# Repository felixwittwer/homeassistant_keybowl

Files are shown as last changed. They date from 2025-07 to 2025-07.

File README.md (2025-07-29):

<br>

<div align="center">

 &nbsp; &nbsp; 

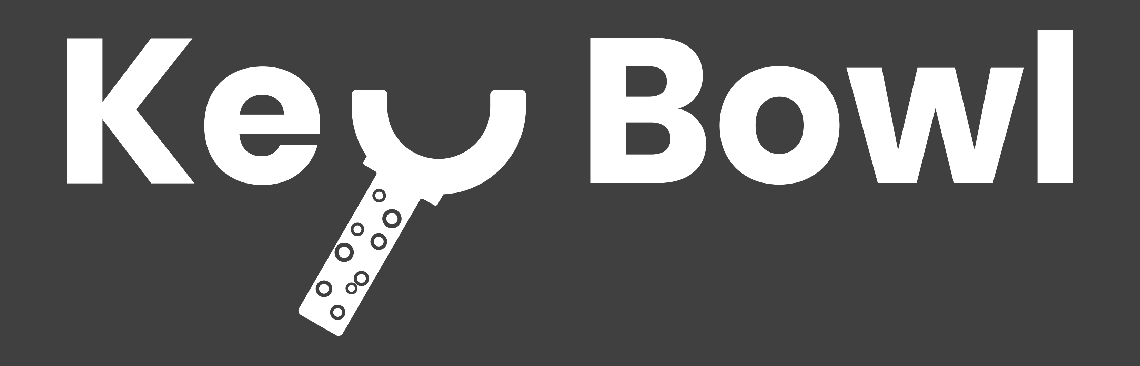
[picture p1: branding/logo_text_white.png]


</div>

<br>

# homeassistant_keybowl
a smart bowl for your keys with Homeassistant integration and a display to show simple dashoards.

## About the project

This project is smart keybowl where you can toss all your keys into and it will show you some interesting stuff from your Homeassistant instance. It simply hits you with the information you need when leaving home or comming back. The shown dashboards are custom for each user and are recognised by the RFID tag on each keychain.

The Keybowl should speed up your everyday routine by presenting you all the information you might have to look up in some app on your phone. For me personally my dashboard will contain a short version of the days timetable for school and its current changes for the day. When comming home it will probably display some stats of my servers.

The Keybowl siply will be a smart everday helper to make my and the life of others a bit easier and reduce the time you have to look up some information on your phone.

## The Project

### PCB

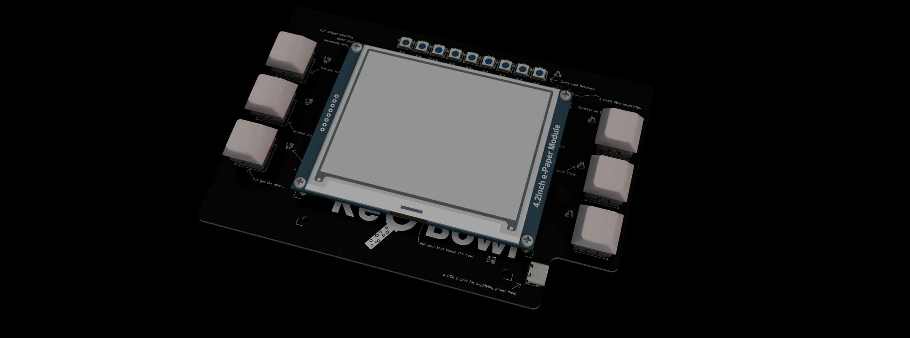
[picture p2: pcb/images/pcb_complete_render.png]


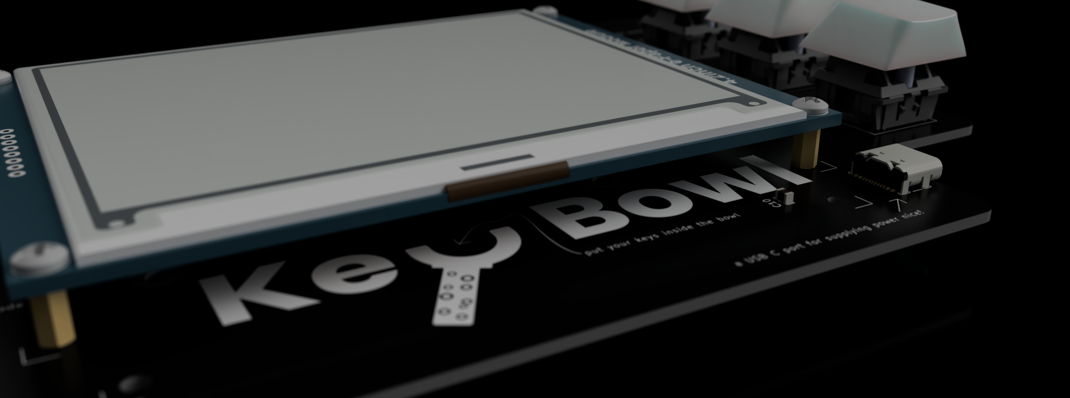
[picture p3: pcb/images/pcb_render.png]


<p float="left">
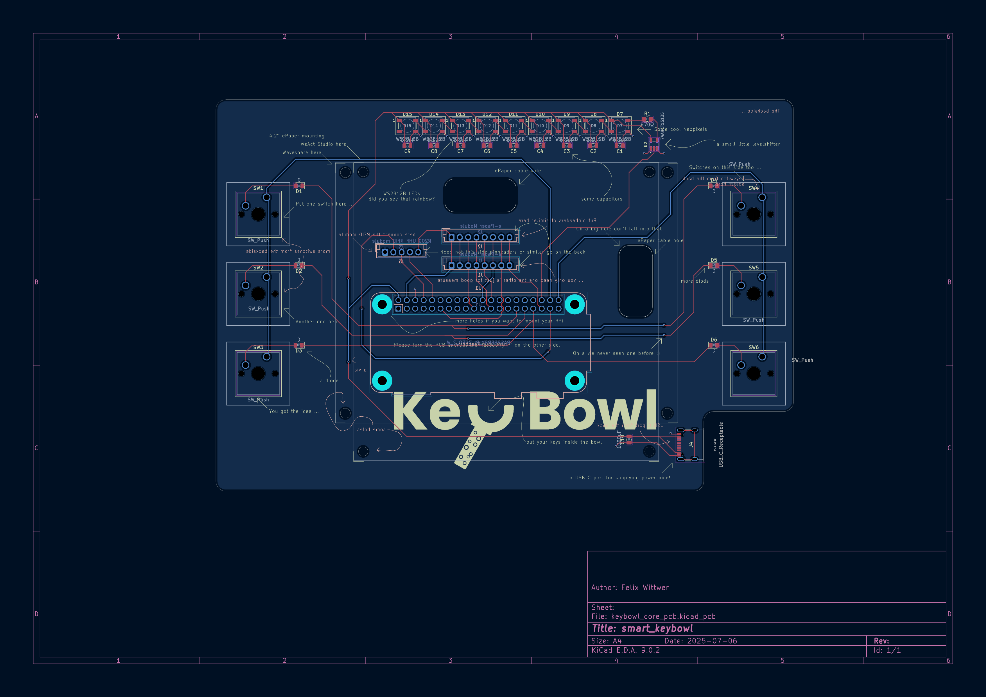
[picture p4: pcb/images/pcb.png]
  
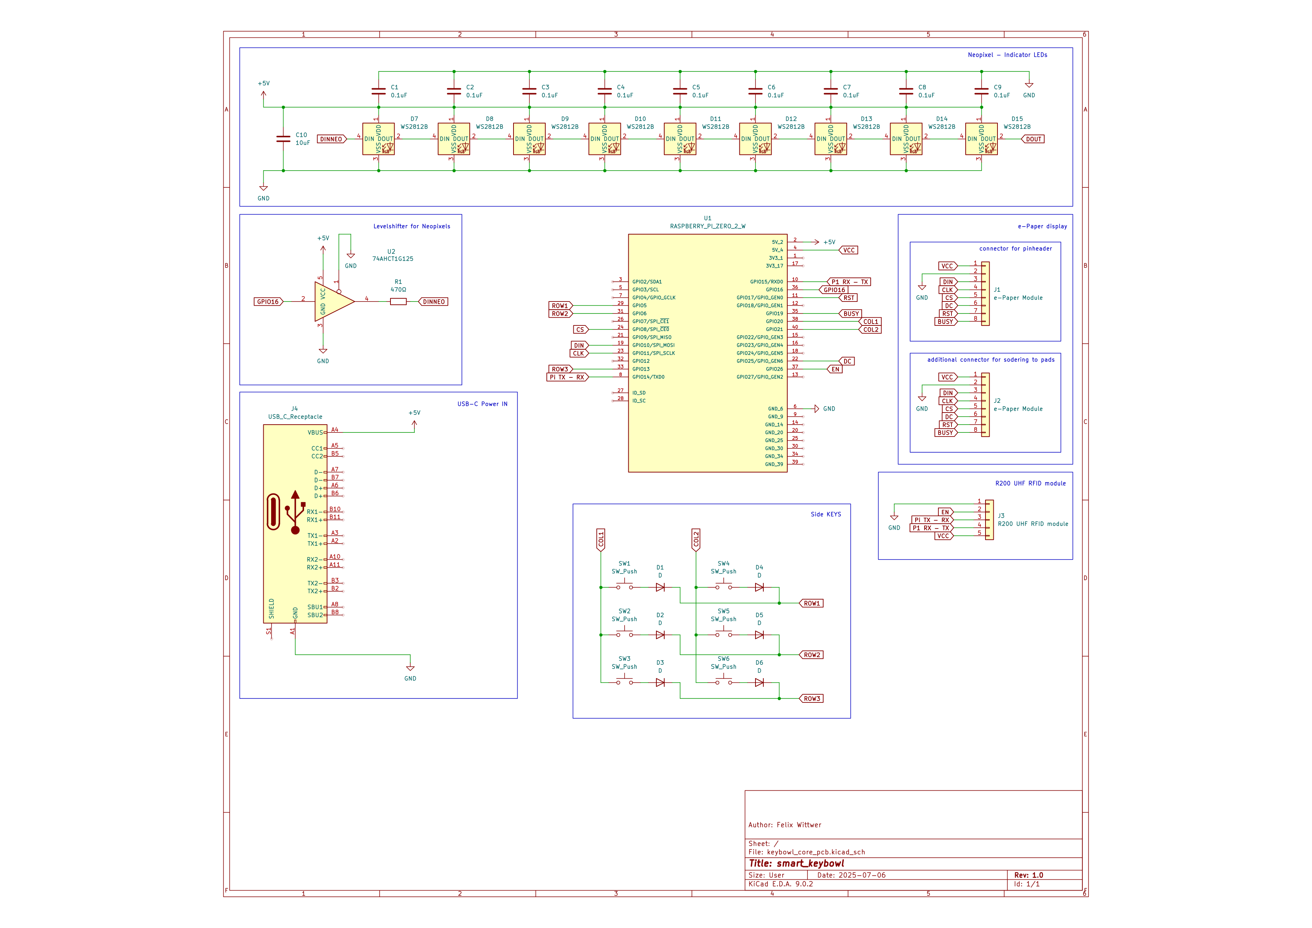
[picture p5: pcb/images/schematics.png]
  
</p>

Be aware that some parts on the rende will not be populated on the PCB because they are not really needed but may be in the future or while I am building the project so for futureprovness the are on in the pcb design and in the rendered images. Have a look at the BOM so se which parts are ment and be aware to bridge the if they are not populated.

### complete assembly

A screenshot of the whole project. Sorry no beautiful render fusions standard wood textures look just ugly :(.

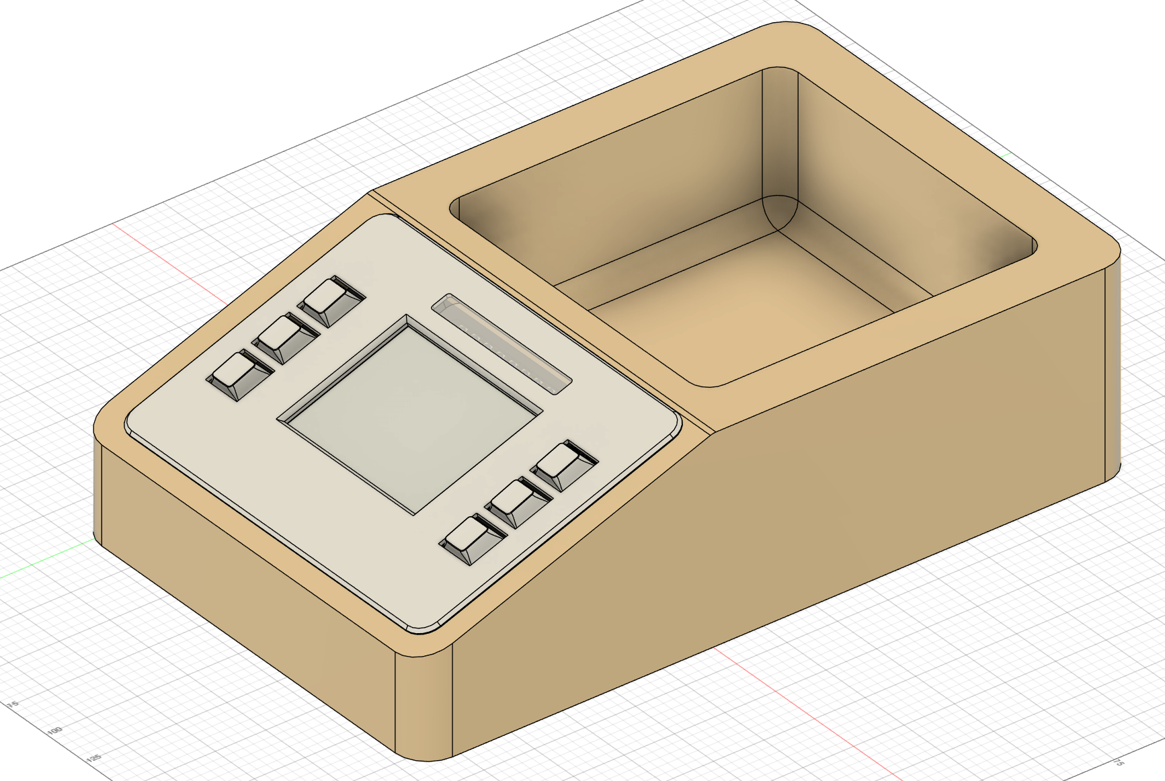
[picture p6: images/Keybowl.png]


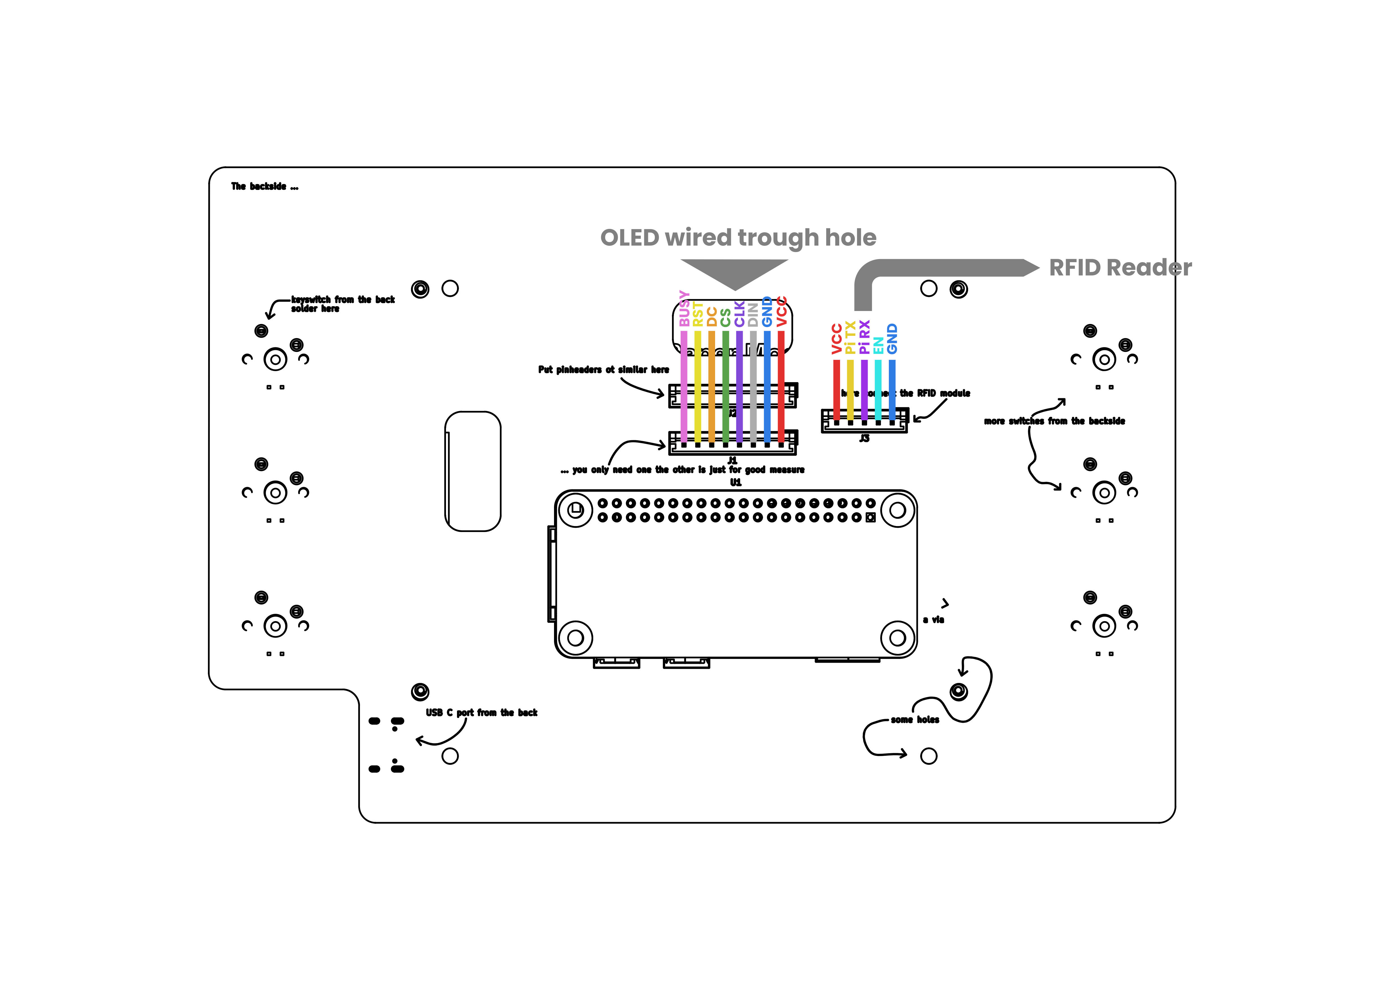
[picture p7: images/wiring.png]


### CAD 

All CAD files can be found inside the [cad](./cad/) directory

[keybowl_complete](./cad/Keybowl%20complete.step) is the whole project and the other files are individual parts of the complete project.

### Firmware

Detailed instructions on how to setup the firmware can be found inside the [firmware folders README](./firmware/README.md)

## BOM

### Aliexpress (for Highway)

**total:** 141.60 USD

| part name | amount | price | link | note |
| --- | --- | ----- | ---- | ---- |
| UHF RFID Module 1dbi 35x35mm | 1 | 39.27 USD | https://de.aliexpress.com/item/1005008307223636.html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 | |
| 4.2inch e-paper | 1 | 29.38 USD | https://de.aliexpress.com/item/1005005825856739.html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 | would have liked to choose another one but waveshare has the best documentation and if you decide to upgrade the displays have the same footprint (upgrading from 4 grayscale to black/white/red possible)|
| Raspberry Pi Zero 2 W | 1 | 20.57 USD | https://de.aliexpress.com/item/1005008147614202.html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 | Pi Zero needed because of Homeassistant integration and connectivity (ESP32-S3 can't quite manage all this stuff together) |
| RFID tags | 5pcs | 0.99 USD | https://de.aliexpress.com/item/1005008292479936.html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
| keyswitches | 6 | 1.19 USD | https://de.aliexpress.com/item/1005005371211477.html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 | come as 10 pcs set |
| basic DSA Keycaps | 6 | 1.19 USD | https://de.aliexpress.com/item/1005006005905021.html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 | come as 20 pcs set |
| PCB and PCBA | 1 | ~ 50 USD |  https://jlcpcb.com/ | price is subject to JLCs review |

**--- PCB Assembly stuff if you want to populate yourself (prices from JLC PCBA) ---**
| part name | amount | price | link | note |
| --- | --- | ----- | ---- | ---- |
| capacitor 0.1 uF | 9 | $0.1254 | https://jlcpcb.com/partdetail/C30926 | ---- |
| WS2812B LEDs | 9 | $2.3471 | https://jlcpcb.com/partdetail/C2843785 | ---- |
| diodes | 6 | $0.4644 | https://jlcpcb.com/partdetail/C24372 | ---- |
| | total | 2,9369 USD

<br>
optional parts (will not be populated) keep in mind to bridge footprints

| part name | amount | price | link | note |
| --- | --- | ----- | ---- | ---- |
| capacitor 10uF  | 1 | $0.1098 | https://jlcpcb.com/partdetail/C39060 | ---- |
| Levelshifter 74AHCT1G125 | 1 | $0.3820 | https://jlcpcb.com/partdetail/C842287 | ---- |
| Resistor 470 ohm | 9 | $0.0300 | https://jlcpcb.com/partdetail/C21266 | ---- |
| usb-c connector | 1 | 0.99 USD | https://de.aliexpress.com/item/1005008164395076.html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 | ----
| | total | 1,5118 USD

**total:** 141.60 USD

<br>
<br>
for people who don't want to order via aliexpress or simply can't here is a BOM with mostly amazon equivalients

### Amazon (mostly)

**total:** 192.48 USD

| part name | amount | price | link | note |
| --- | --- | ----- | ---- | ---- |
| UHF RFID Module 1dbi 35x35mm | 1 | 39.27 USD | https://de.aliexpress.com/item/1005008307223636.html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 | | 
| 4.2inch e-paper | 1 | 54.08 USD | https://www.amazon.de/dp/B074NR1SW2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 | would have liked to choose another one but waveshare has the best documentation and if you decide to upgrade the displays have the same footprint (upgrading from 4 grayscale to black/white/red possible)| 
| Raspberry Pi Zero 2 W | 1 | 26.93 USD | https://www.amazon.de/Raspberry-Pi-Zero-2-W/dp/B09KLVX4RT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 | Pi Zero needed because of Homeassistant integration and connectivity (ESP32-S3 can't quite manage all this stuff together) |
| RFID tags | 5pcs | 7.95 USD | https://www.amazon.de/YARONGTECH%C2%AE-RFID-13-56-MIFARE-Classic/dp/B0749LSMLH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
| keyswitches | 6 | 8.55 USD | https://www.amazon.de/Topiky-mechanische-Tastatur-Schalter-RGB-Serie-default/dp/B07Q6YJ2GS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 | come as 10 pcs set |
| basic DSA Keycaps | 6 | 5.70 USD | https://www.amazon.de/Transparent-Keycaps-Mechanical-Keyboard-Clearance/dp/B0CJLS9GGP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 | come as 10 pcs set |
| PCB and PCBA | 1 | ~ 50 USD |  https://jlcpcb.com/ | price is subject to JLCs review |

**total:** 192.48 USD

## Credits

Raspberry Pi Zero Symbol, Footprint and 3D-Model for KiCad: https://www.snapeda.com/parts/RASPBERRY%20PI%20ZERO%202%20W/Raspberry%20Pi/view-part/?welcome=home

Waveshare 4.2inch e-Paper Module CAD: https://grabcad.com/library/waveshare-4-2-e-paper-module-1

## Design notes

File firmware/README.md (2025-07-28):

# Firmware

This is a small guide about the structure of the firmware and how to install it on your pi zero 2.

## structure

low level code for all the individual parts

**-> components**

some routines

**-> routines**

the dashboards to show

**-> dashboards**

besides the folder there is the **main.py** which is the main script that needs to be executed. 

## setup the firmware

### General and Python Setup 

Install Raspberry Pi OS Lite

``` bash
sudo apt update && sudo apt upgrade -y
sudo apt install python3 python3-pip git
```

### clone the Repo

``` bash
git clone https://github.com/felixwittwer/homeassistant_keybowl.git
```

``` bash
cd homeassistant_keybowl
```

### Install the required python packages

``` bash
pip install -r requirements.txt
```

### Enable I2C and Serial

``` bash
sudo raspi-config
```

- (enable I2C)
- enable Serial (disable shell, enable hardware serial)

Reboot!

### SPI Setup

- Make sure SPI is enabled on your Pi

``` bash
sudo raspi-config
```
(Interface Options -> SPI -> Enable)

Reboot if asked!

- confirm SPI device nodes:
``` bash
ls /dev/spidev0.*
```

### MQTT Setup for Homeassistant

(this command is not really neadded when you installed everything via the requirements.txt)

``` bash
pip install paho-mqtt
```

Inside Homeassistant make sure you have a MQTT Broker like Mosquitto installed and enabled.

### Neopixel Setup

``` bash
sudo pip install rpi_ws281x adafruit-circuitpython-neopixel
sudo python -m pip install --force-reinstall adafruit-blinka
```

### Run the firmware

``` bash
python3 main.py
```

### Setup autostart on boot

open with

``` bash
sudo nano /etc/rc.local
```

and add :
``` bash
python3 /home/pi/homeassistant_keybowl/main.py 
```

above exit 0

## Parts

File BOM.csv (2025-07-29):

part name | amount | price | link | note
UHF RFID Module 1dbi 35x35mm | 1 | 39.27 USD | https://de.aliexpress.com/item/1005008307223636.html?pdp_ext_f={"order"%3A"8"%2C"eval"%3A"1"}&utparam-url=scene%3Asearch|query_from%3A
4.2inch e-paper | 1 | 29.38 USD | https://de.aliexpress.com/item/1005005825856739.html?pdp_ext_f={"order"%3A"13"%2C"eval"%3A"1"}&utparam-url=scene%3Asearch|query_from%3A | would have liked to choose another one but waveshare has the best documentation and if you decide to upgrade the displays have the same footprint (upgrading from 4 grayscale to black/white/red possible)
Raspberry Pi Zero 2 W | 1 | 20.57 USD | https://de.aliexpress.com/item/1005008147614202.html?pdp_ext_f={"order"%3A"141"%2C"eval"%3A"1"}&utparam-url=scene%3Asearch|query_from%3A
RFID tags | 5 | 0.99 USD | https://de.aliexpress.com/item/1005008292479936.html?pdp_ext_f={"order"%3A"24"%2C"eval"%3A"1"}&utparam-url=scene%3Asearch|query_from%3A | Pi Zero needed because of Homeassistant integration and connectivity (ESP32-S3 can't quite manage all this stuff together)
keyswitches | 6 | 1.19 USD | https://de.aliexpress.com/item/1005005371211477.html?pdp_ext_f={"order"%3A"13"%2C"eval"%3A"1"}&utparam-url=scene%3Asearch|query_from%3A | come as 20 pcs set
basic DSA Keycaps | 6 | 1.19 USD | https://de.aliexpress.com/item/1005006005905021.html?pdp_ext_f={"order"%3A"525"%2C"eval"%3A"1"}&utparam-url=scene%3Asearch|query_from%3A | come as 20 pcs set
PCB and PCBA | 1 | ~ 50 USD | https://jlcpcb.com/ | price is subject to JLCs review
total |  | 141.16 USD

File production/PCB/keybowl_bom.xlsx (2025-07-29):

Comment | Designator | Footprint | JLCPCB Part #?optional?
0.1uF | C7,C4,C5,C8,C6,C1,C9,C2,C3 | C_0805_2012Metric | C30926
WS2812B | D9,D11,D10,D7,D12,D13,D8,D15,D14 | LED_WS2812B_PLCC4_5.0x5.0mm_P3.2mm | C2843785
D | D5,D2,D3,D4,D1,D6 | D_0805_2012Metric | C24372
10uF | C10 | C_0805_2012Metric | C39060
74AHCT1G125 | U2 | SOT95P280X145-5N | C842287
470ohm | R1 | R_0805_2012Metric_Pad1.20x1.40mm_HandSolder | C21266

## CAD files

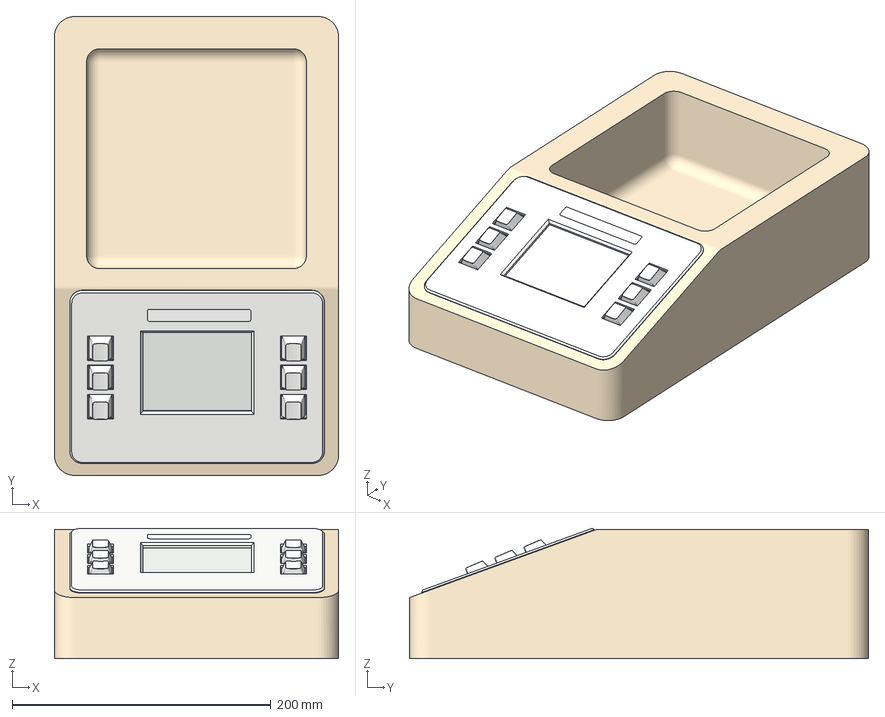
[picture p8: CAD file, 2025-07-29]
cad/Keybowl complete.3mf
220.0 x 355.0 x 100.8 mm
Körper1 x 107
Körper10 x 10
Körper100 x 3
Körper101 x 3
Körper102 x 3
Körper103 x 3
Körper104 x 3
Körper105 x 3
Körper106 x 3
Körper107 x 3
Körper108 x 3
Körper109 x 3
Körper11 x 10
Körper110 x 3
Körper111 x 3
Körper112 x 3
Körper113 x 3
Körper114 x 3
Körper115 x 3
Körper116 x 3
Körper117 x 3
Körper118 x 3
Körper119 x 3
Körper12 x 10
Körper120 x 3
Körper121 x 3
Körper122 x 3
Körper123 x 3
Körper124 x 3
Körper125 x 3
Körper126 x 3
Körper127 x 3
Körper128 x 3
Körper129 x 3
Körper13 x 10
Körper130 x 3
Körper131 x 3
Körper132 x 3
Körper133 x 3
Körper134 x 3
Körper135 x 3
Körper136 x 3
Körper137 x 3
Körper138 x 3
Körper139 x 3
Körper14 x 10
Körper140 x 3
Körper141 x 3
Körper142 x 3
Körper143 x 3
Körper144 x 3
Körper145 x 3
Körper146 x 3
Körper147 x 3
Körper148 x 3
Körper149 x 3
Körper15 x 10
Körper150 x 3
Körper151 x 3
Körper152 x 3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

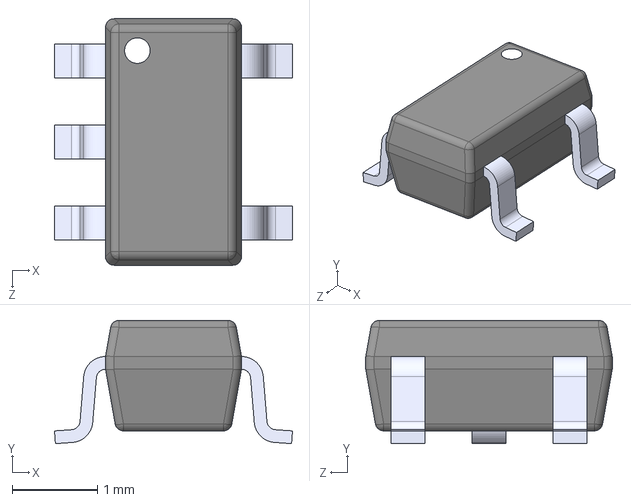
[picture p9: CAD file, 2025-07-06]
pcb/keybowl_core_pcb/SN74AHCT1G125DBVR/SN74AHCT1G125DBVR.step
2.80 x 1.45 x 2.90 mm

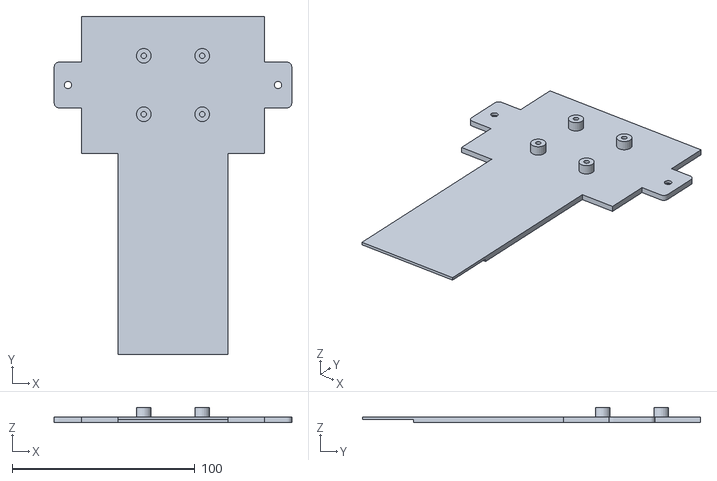
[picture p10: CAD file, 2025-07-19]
production/3D printing/rfid_support.stl
130.0 x 185.0 x 8.00

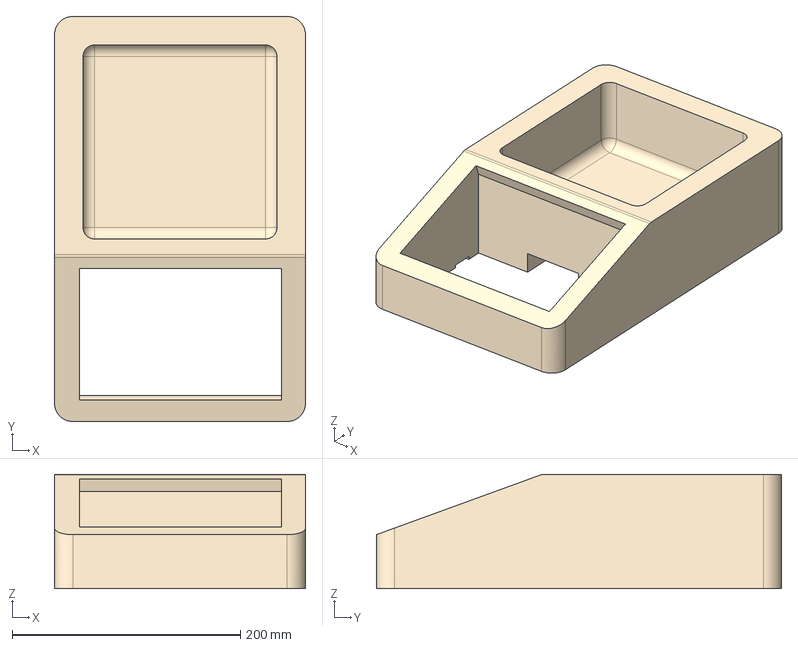
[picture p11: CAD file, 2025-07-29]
cad/bowl.step
220.0 x 355.0 x 100.0 mm

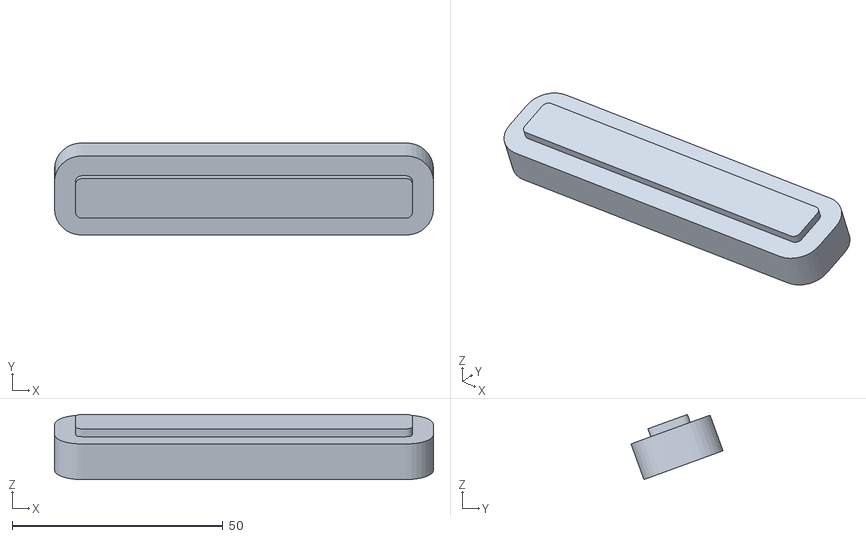
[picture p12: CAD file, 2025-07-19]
production/3D printing/nepixel_diffusor.stl
90.0 x 21.9 x 15.5

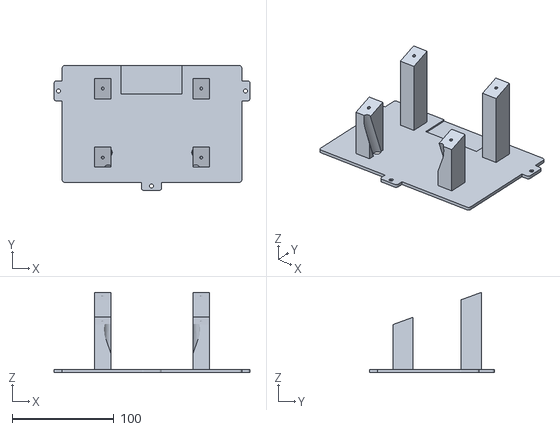
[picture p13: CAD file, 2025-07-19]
production/3D printing/pcb_support.stl
193.0 x 123.0 x 78.9

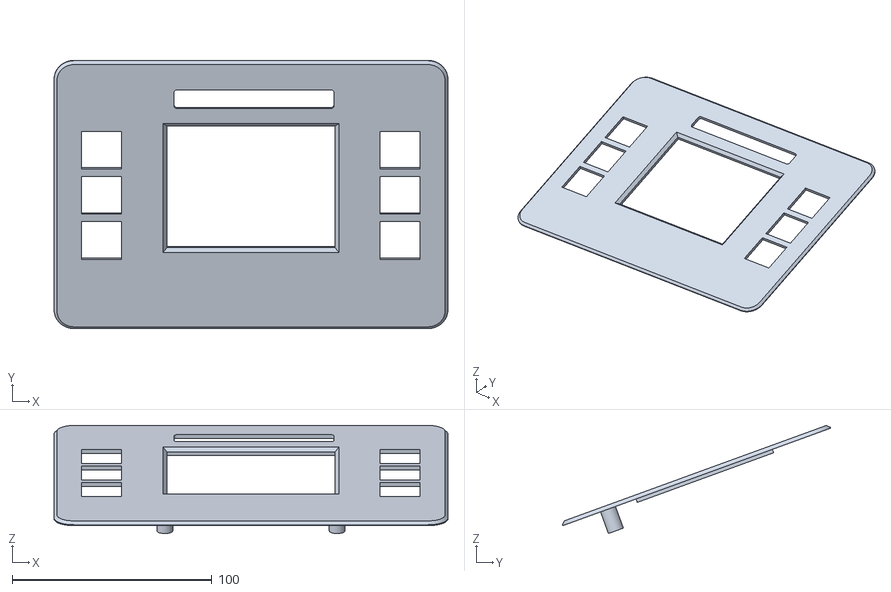
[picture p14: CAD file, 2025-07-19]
production/3D printing/bezzle.stl
197.0 x 134.1 x 54.0

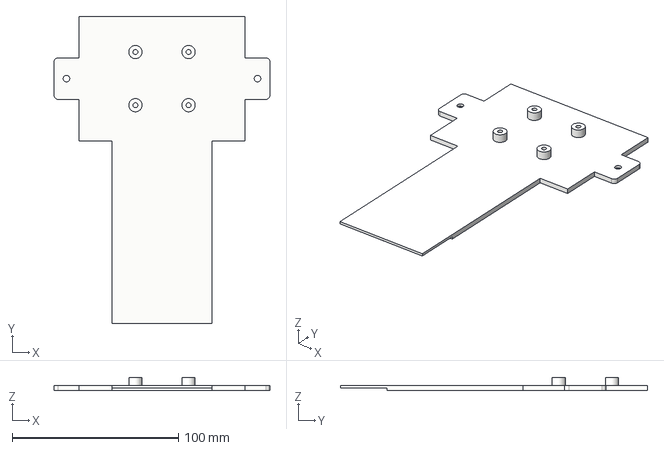
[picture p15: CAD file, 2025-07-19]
cad/rfid_support.step
130.0 x 185.0 x 8.00 mm

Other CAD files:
cad/neopixel_diffusor.step
cad/pcb_support.step
cad/bezzle.step

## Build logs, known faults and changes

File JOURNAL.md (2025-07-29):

---
title: "Homeassistant KEYBOWL"
author: "Felix Wittwer (fegolix)"
description: "A keybowl designed for all your keys. But smart."
created_at: "2024-07-06"
---

# Journal

Here you can see a documentation of the entire development process.

**Total hours spent: 26h**

## July 6th (7h)

### Session 1 (2h) getting the idea, researching

After searcing for my keys and not finding them in our "key bowl" I got the idea of a smart solution for our keys. And even better how to integrate that into Homeassistant. Forst of all the concept. So the normal non smart version is preitty simple, just toss all your keys into a borwl/ basket but what if every keychain had an RFID tag on it? This would allow for thracking the keys not neccesarily to spy on wh is home wut to knwo where the keys are. To step it up a bit this could also be integrated into Homeassistant with a small display that shows some data/dashboard per user. Everyone has his own keychain so I can track who tossed his key in or took it out. And based on that information everybody gets shown his own personal dashboard. For one it might be stats about our greenhouse for the othe their timetable and current changes of it right in the morning before school.

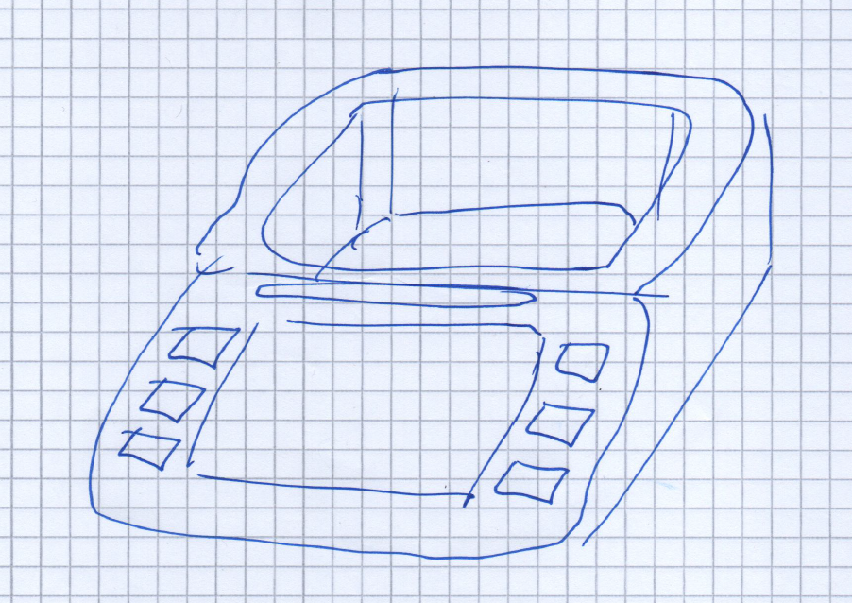
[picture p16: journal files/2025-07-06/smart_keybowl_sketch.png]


<br>

I wanted a simple non distracting and simple solution that doesn't uses to much power and in standby mode maybe can be used as a clock. So I opted for a 4.2 inch e-Paper display and a raspberry Pi Zero 2 which is relatively low cost but has enough power to handle all the stuff of the display, additional keys and RFID reader and can render beautiful layouts on the screen. An ESP32-S3 simply cant handel all of that in an easy way. Another chalenge was finding the right module and corresponding RFID Tags. NFC simply wouldn't cut it here. I needed a solution that can read multiple tags at one inside a pile and that without errors. This lead me to the R200 module a UHF RFID Reader.

### Session 2 (5h) starting PCB design

After researching all the parts I started with the core PCB which is kind of a HAT for the Raspberry Pi Zero 2 and will be in the middle of the case. Everything else will be designed arround it. To make it a bit extra I added a bar of neopixels above the display this will later be usefull to show status or be indicator LEDs. Because I quite like habtical buttons I added three on each side of the display. These will later be for navigating on the display of showing specific dashboards. These additions make the whole thing a bit mode interesting so now it is not "just a display" :).

This time I really tried making my schematics a bit better than the last one. I think it is quite organised. Another challenge for me was learing on how to use a ground plane which I have never done befoder but eventually got it working.

<p float="left">
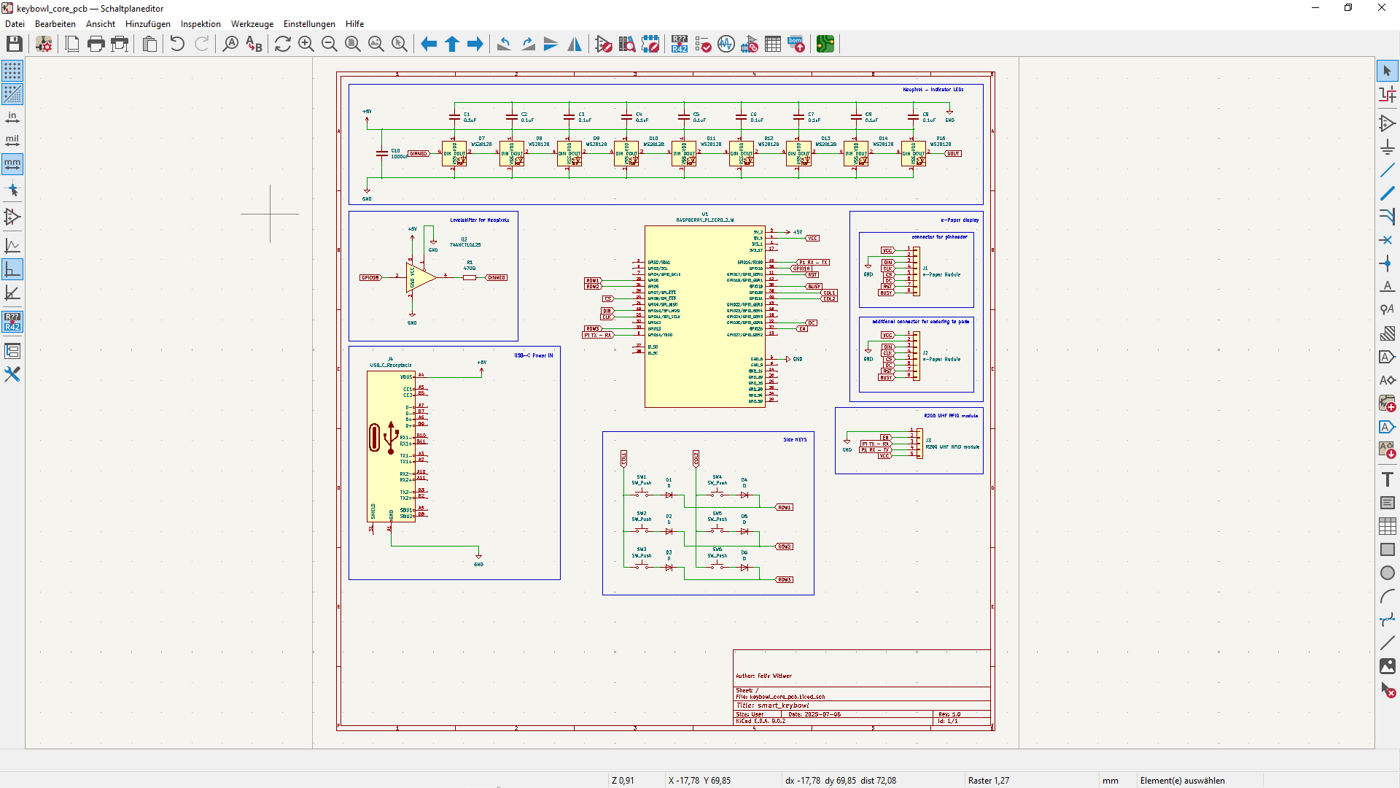
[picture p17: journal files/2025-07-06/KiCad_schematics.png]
  
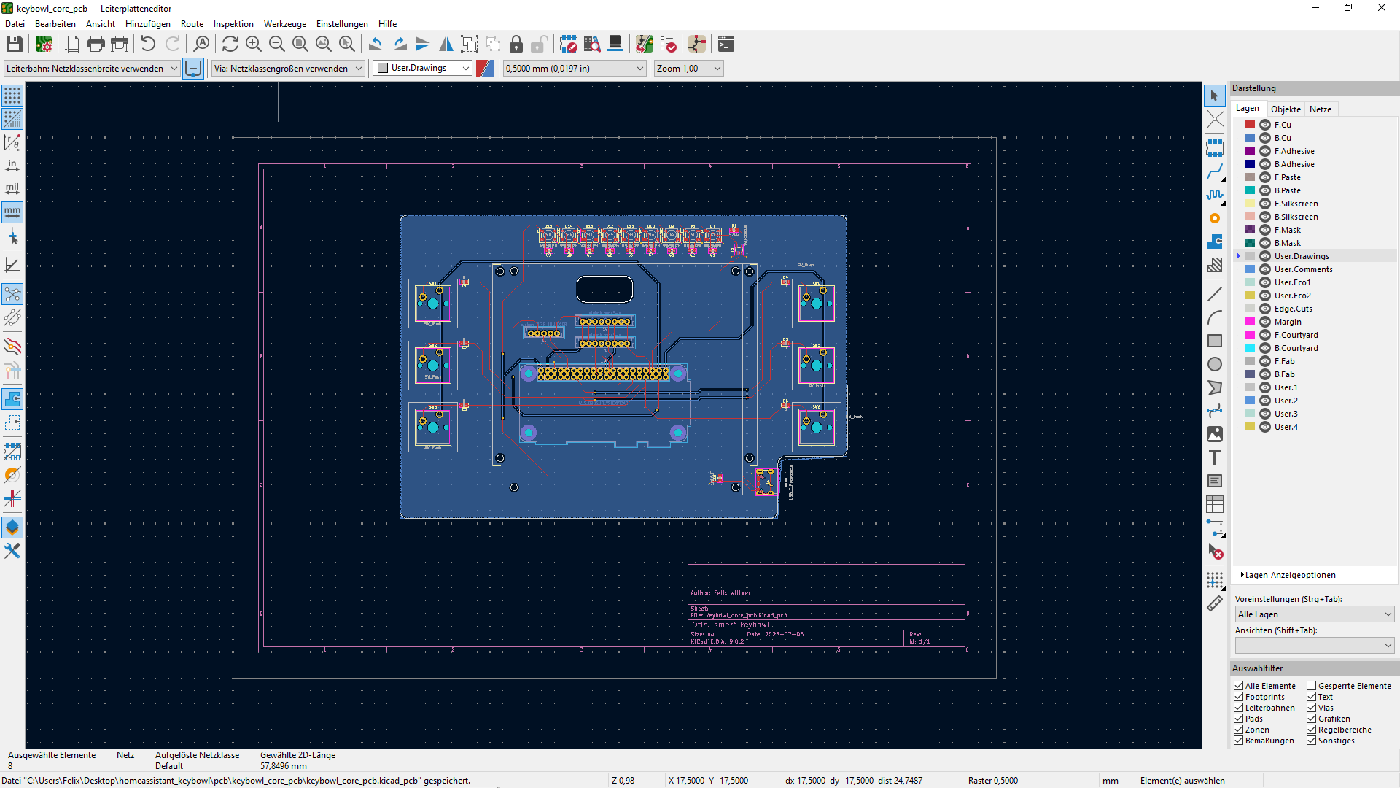
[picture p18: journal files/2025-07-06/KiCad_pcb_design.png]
  
</p>

## July 8th (2h)

### Session 1 (1h) adding some branding

Every project need some branding and I need some logos to make the PCB beautiful :). Logo is made with Inkscape.

<p float="left">
  
</p>

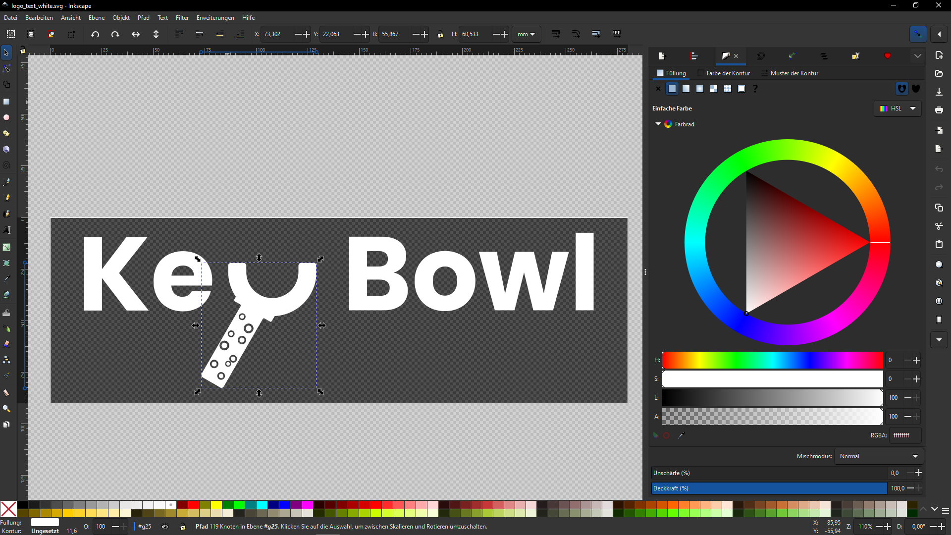
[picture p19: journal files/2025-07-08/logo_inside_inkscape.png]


### Session 2 (1h) working on the PCB

Now with a cool logo I could work further on the PCB. After adding the logo it seemed still a bit empty to me so I added some cool notes. If somebody else that me is going to assemlble this he is going to have some fun. AN jeah I defenitely discovered the path feature for the siklscreen lines/arrows. Some engenieet at JLC is going to get crazy after seeing my silkscreen :).

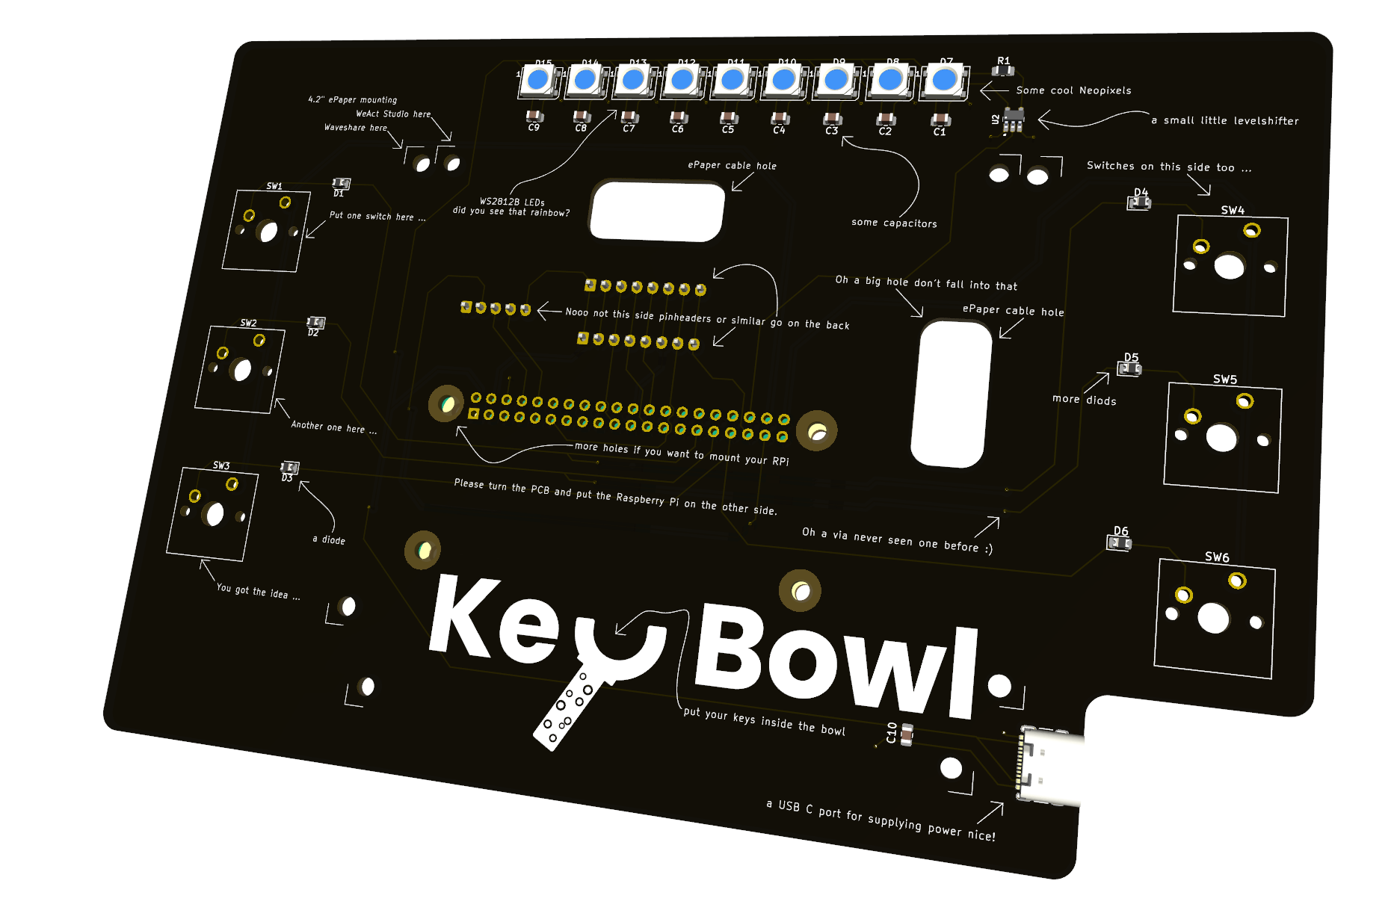
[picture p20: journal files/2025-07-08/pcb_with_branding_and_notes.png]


## July 18th (1h) assemble pcb in Fusion

Today I just exported the PCB from KiCad as a STEP to Fusion and sarted putting all the pars on it. The next step will be to design the keybowl itself and place the PCB inside. The Keybowl itself will porbably be made out of Wood with some small 3D printed parts like a bezzle around the screen and keyswitches.

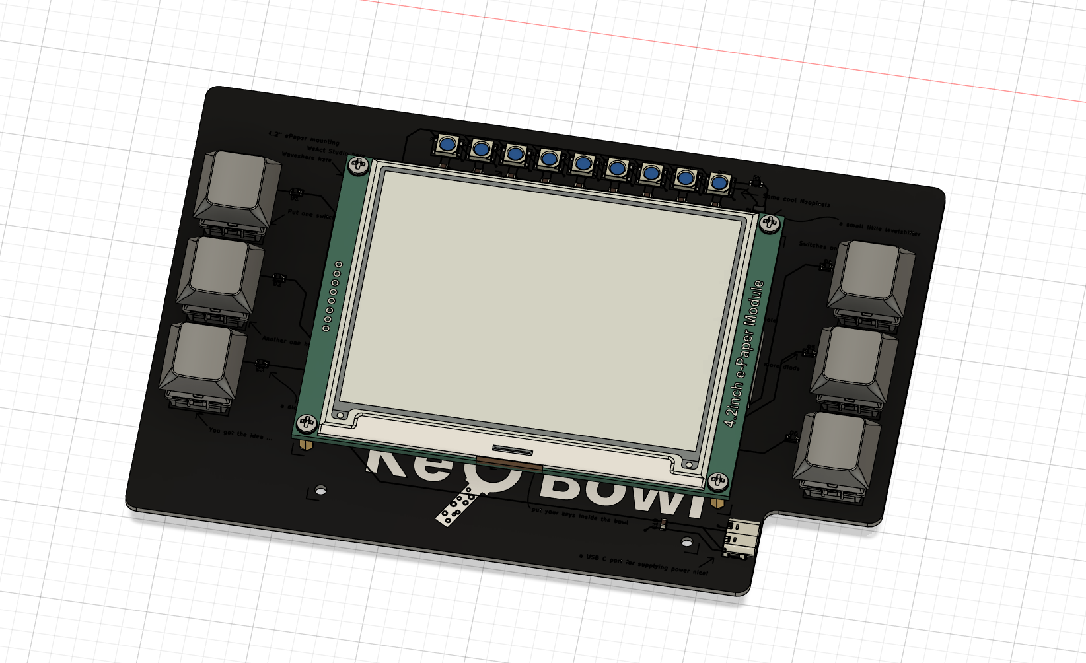
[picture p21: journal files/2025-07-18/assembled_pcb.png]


## July 19th (5h)

### Session 1 (4h) modeling the case

After creating a model of the assembled PCB I designed a housing around it. The main hosusing will be made out of wood only the parts for holding the PCb, RFID reader and the bezzle will be 3D printed. I designed the bezzle in such a way that it lays over the part that will be removed with a roter so if I mess up there it is at least not hidden. The parts fo the PCB and RFID mounting are also seperate to that these can be changed independently. So if someone chooses a bigger RFID reader not the whole structer needs to be reprinted. It also took me a while to figure out how I can mount everything while also making it possible to assemble. If the PCB is mouted inside the housing you can not reach the screws of the bezzle. Therefore I mad some additional holes inside the mounting to make the screws actually reachable.  

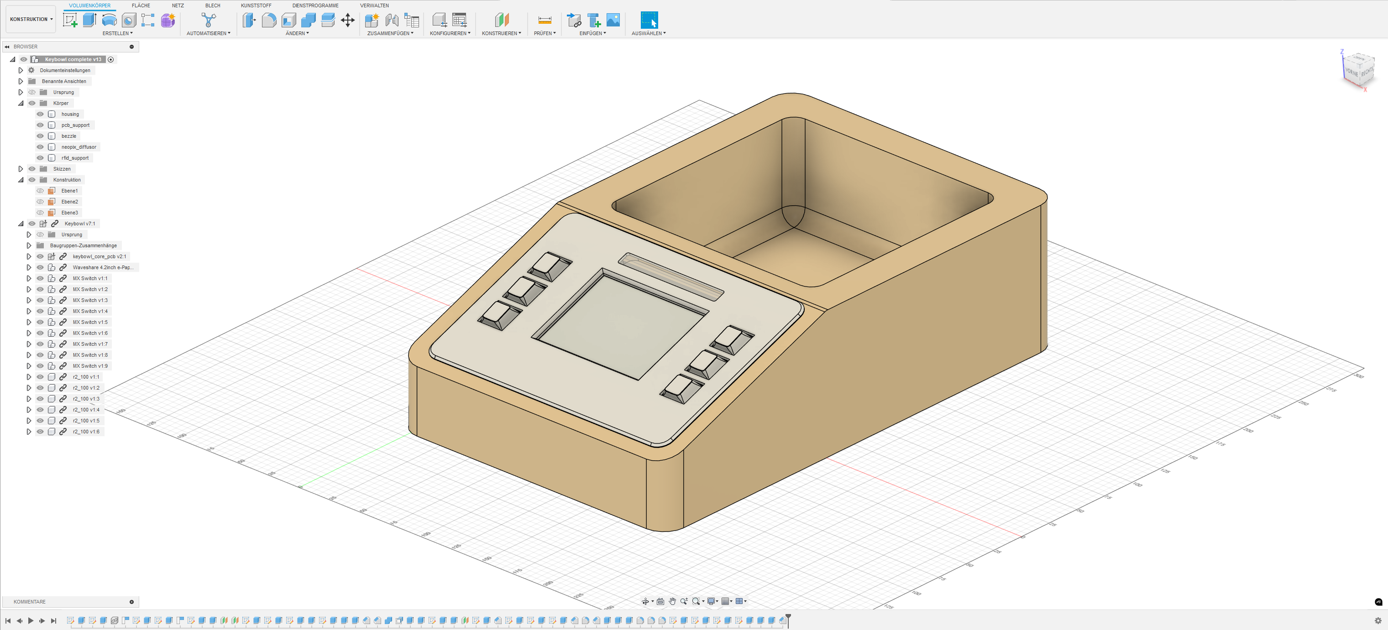
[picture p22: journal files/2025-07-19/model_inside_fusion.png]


<p float="left">
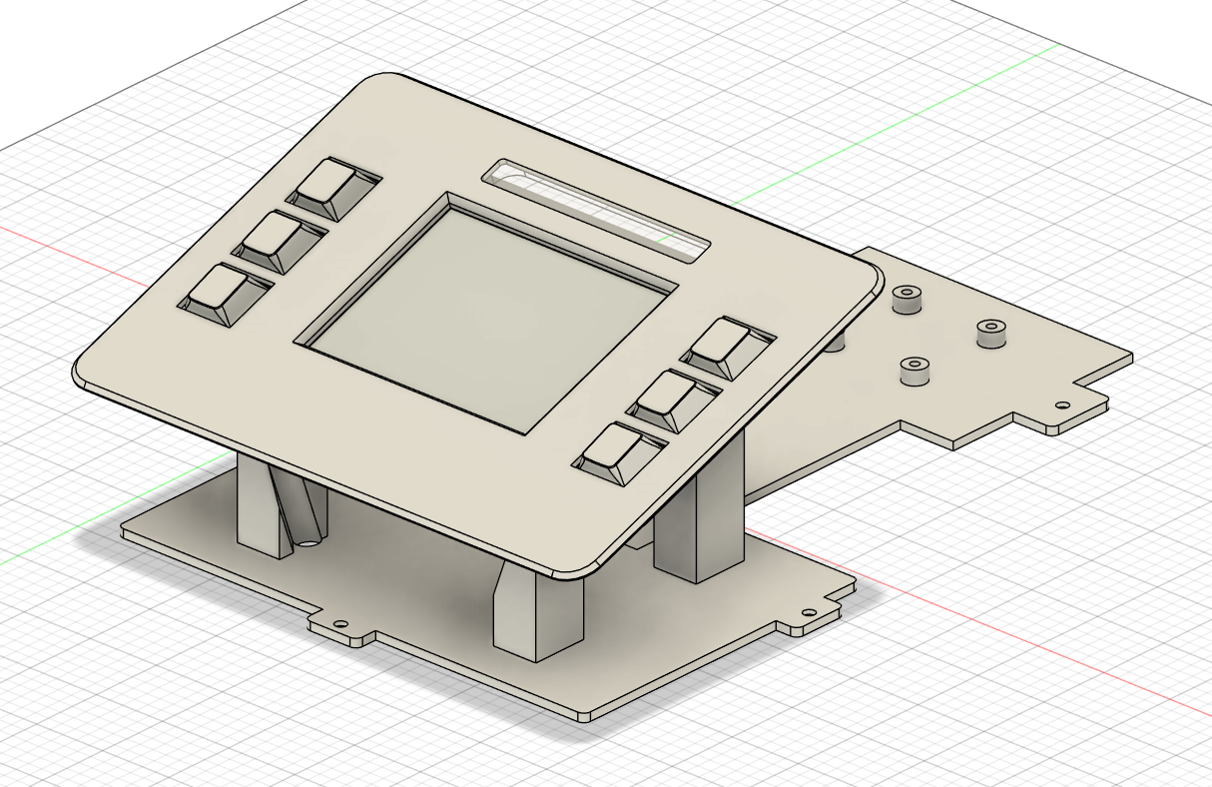
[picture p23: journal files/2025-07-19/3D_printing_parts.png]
  
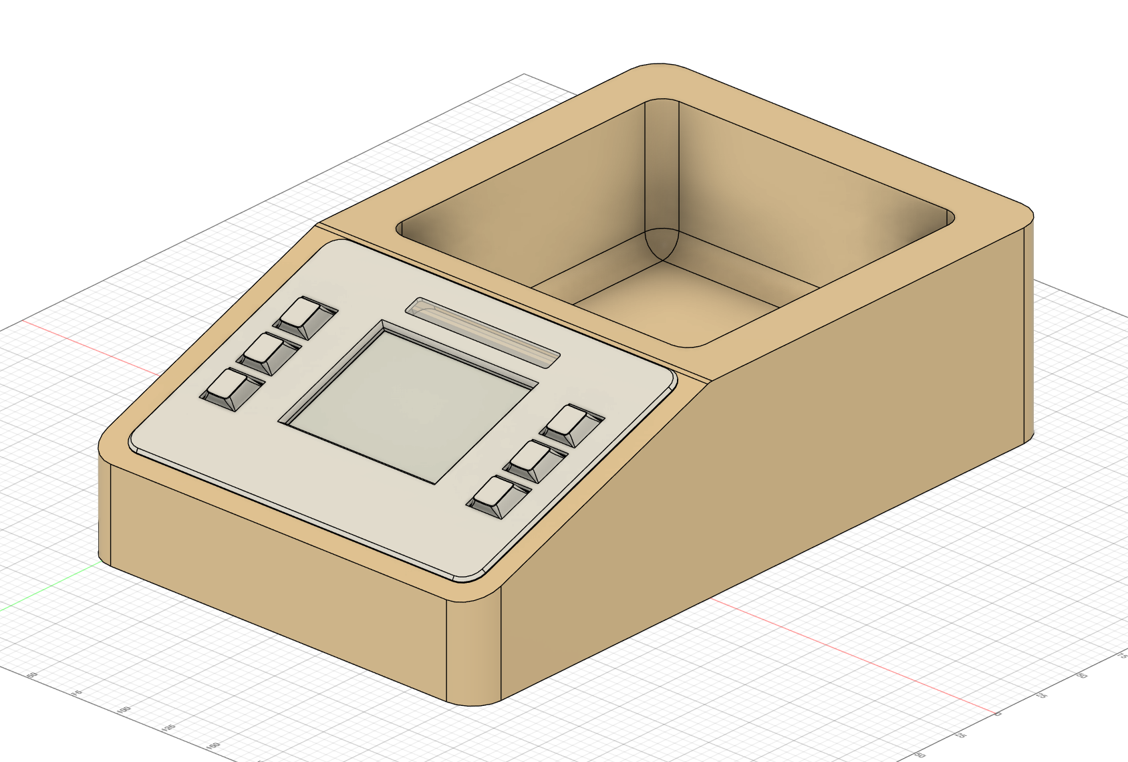
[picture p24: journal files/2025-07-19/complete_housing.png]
  
</p>

### Session 2 (1h) creating production files and manufacturing instructions

I hav now created a stl file and step file for each part so that they can easily be 3D printed. Because recreating the woodden base if you have not designed it is pretty difficult I created some drawings with whom anybody can build the main housing. If you have large enough 3D printer you could probably also just print it but wood looks a bit nicer.

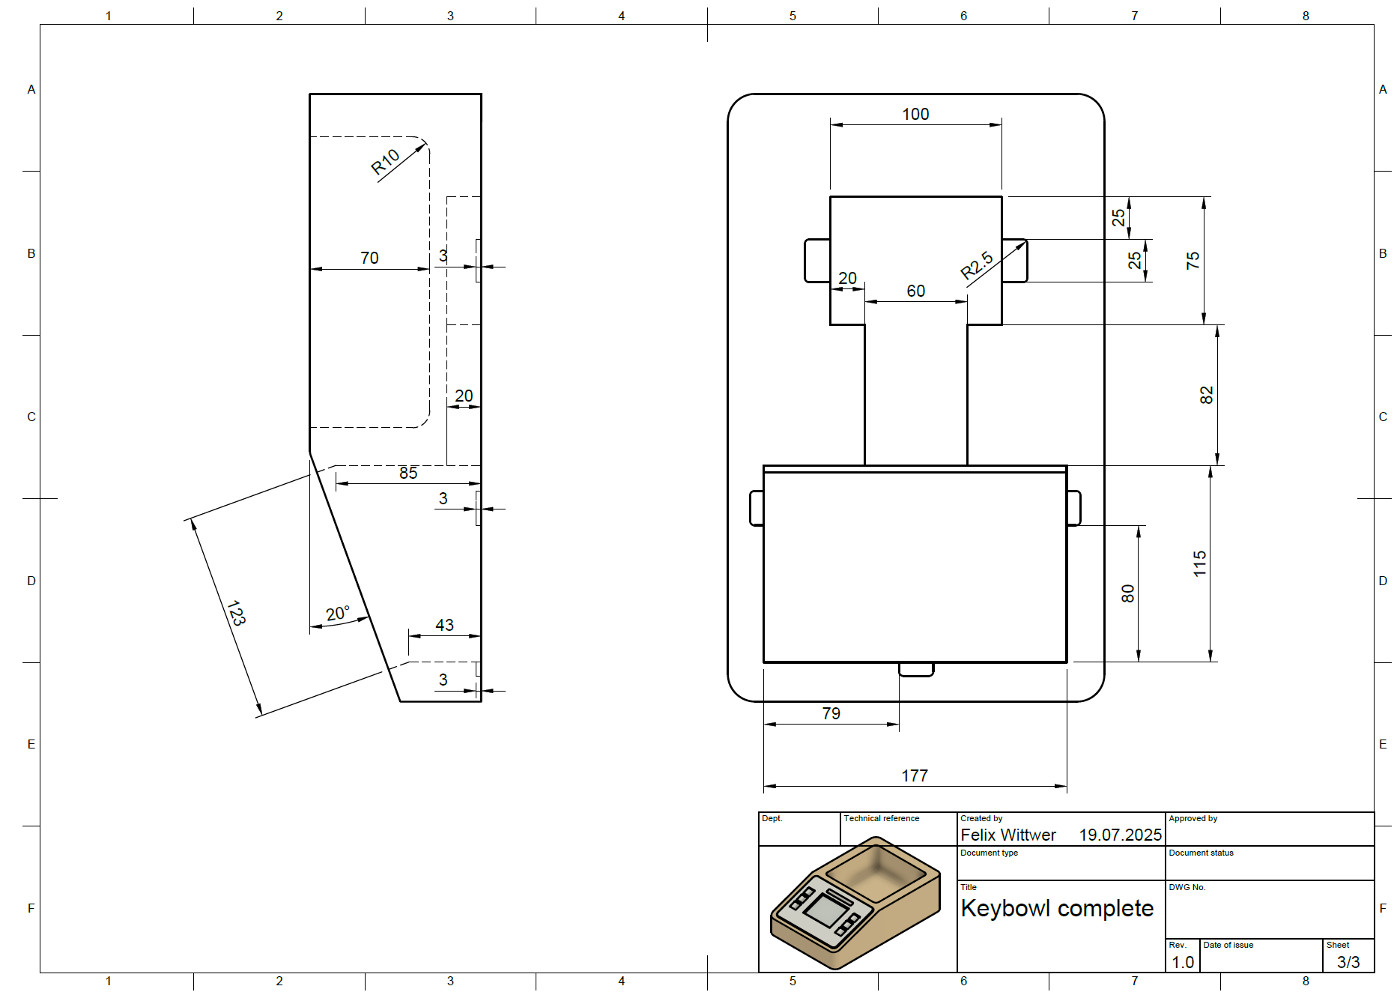
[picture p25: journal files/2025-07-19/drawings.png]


## July 28th (7h) writing the firmware

Since all the CAD and electronics are finished I only needed to write some firmware to make the project almost complete in terms of the planing phase. Say so it is not the first time for me using Python but I am defenitely no expert and creating a clean structure that I myself and also others could understand was dificult but I think I managed to put something good together. The firmware is relatively well structured and I added a README just for setting up and installing the firmware on the Pi Zero. During the process of writing the Firmware I even catched a small error inside my scematics. Fortunately it was not something that would have broken the pcb but defenitely something that willl have confused someone that knows how to read schematics. :)

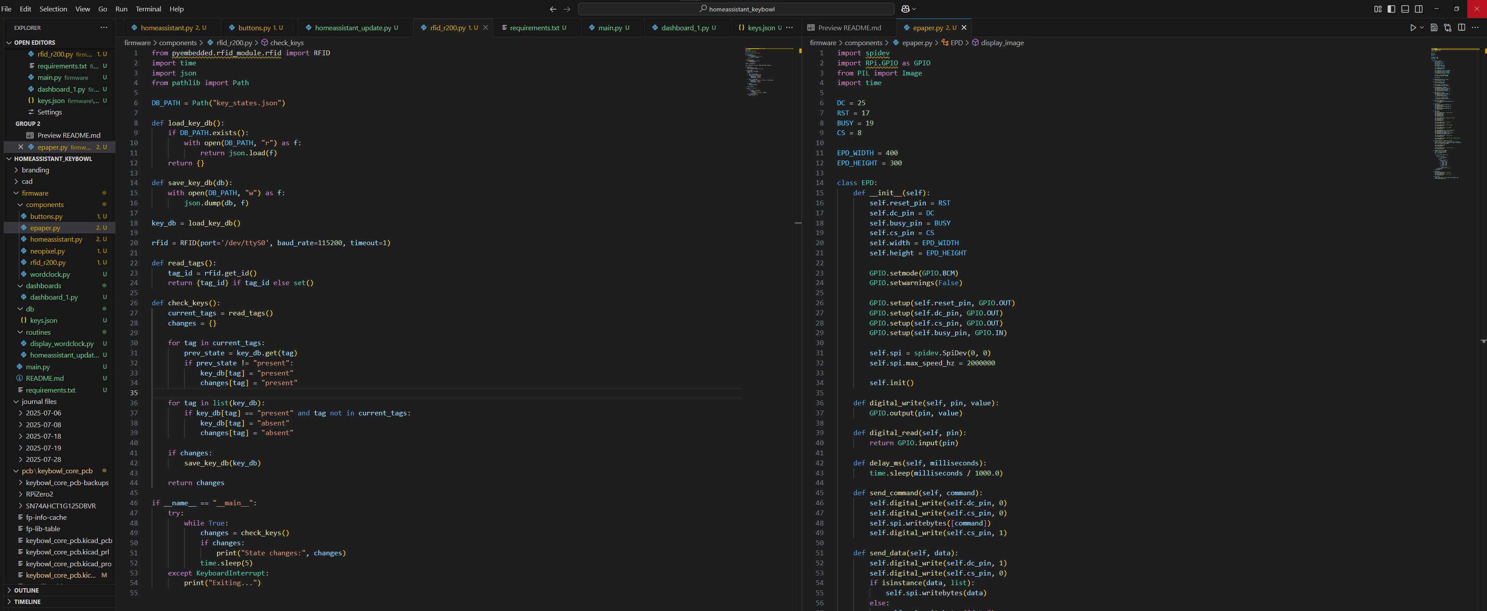
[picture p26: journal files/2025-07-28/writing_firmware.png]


## July 29th (2h)

### Session 1 (2h) creating production files especially for PCB assembly

The final thing taht needed to be done for production are the gerber, bom an placement files for the PCB. creating gerbers is a nobrainer for me since I have done it many times but making everything work for PCBA is sometimes a bit difficult. numbers have problems with their seperators, rotation or and placement of the part is off ot the package size is not matching. In the end it took me two hours to get everything right.

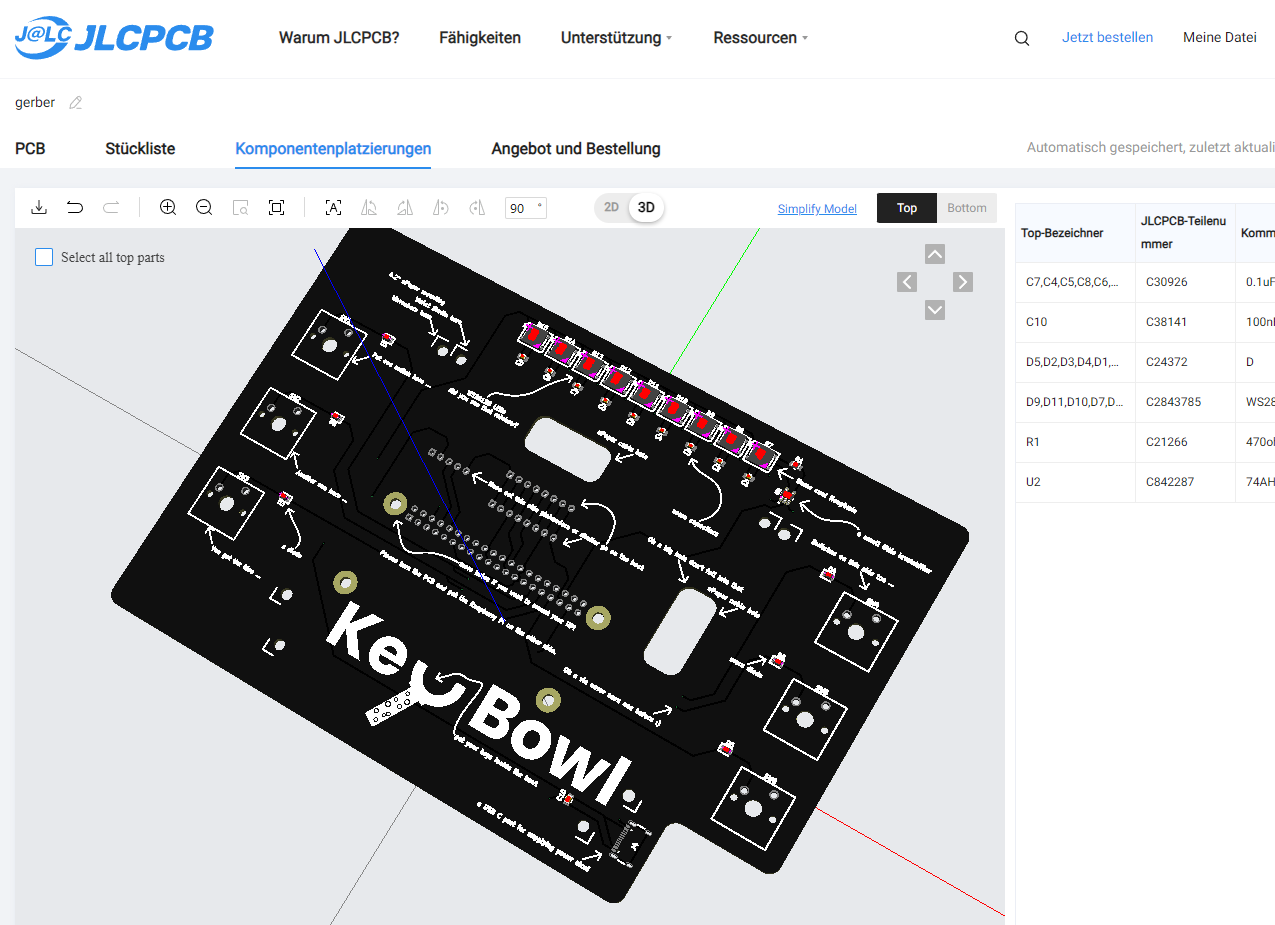
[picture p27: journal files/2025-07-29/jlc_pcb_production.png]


### Session 2 (2h) getting ready for submission

For the final submission there are some things that need to be done besides creating the production files. I also wanted to create some cool renders for my README to show off the PCB I made. The rendering of wood in Fusion turned out to be ugly so I decided on just including a screenshot of the final CAD model.



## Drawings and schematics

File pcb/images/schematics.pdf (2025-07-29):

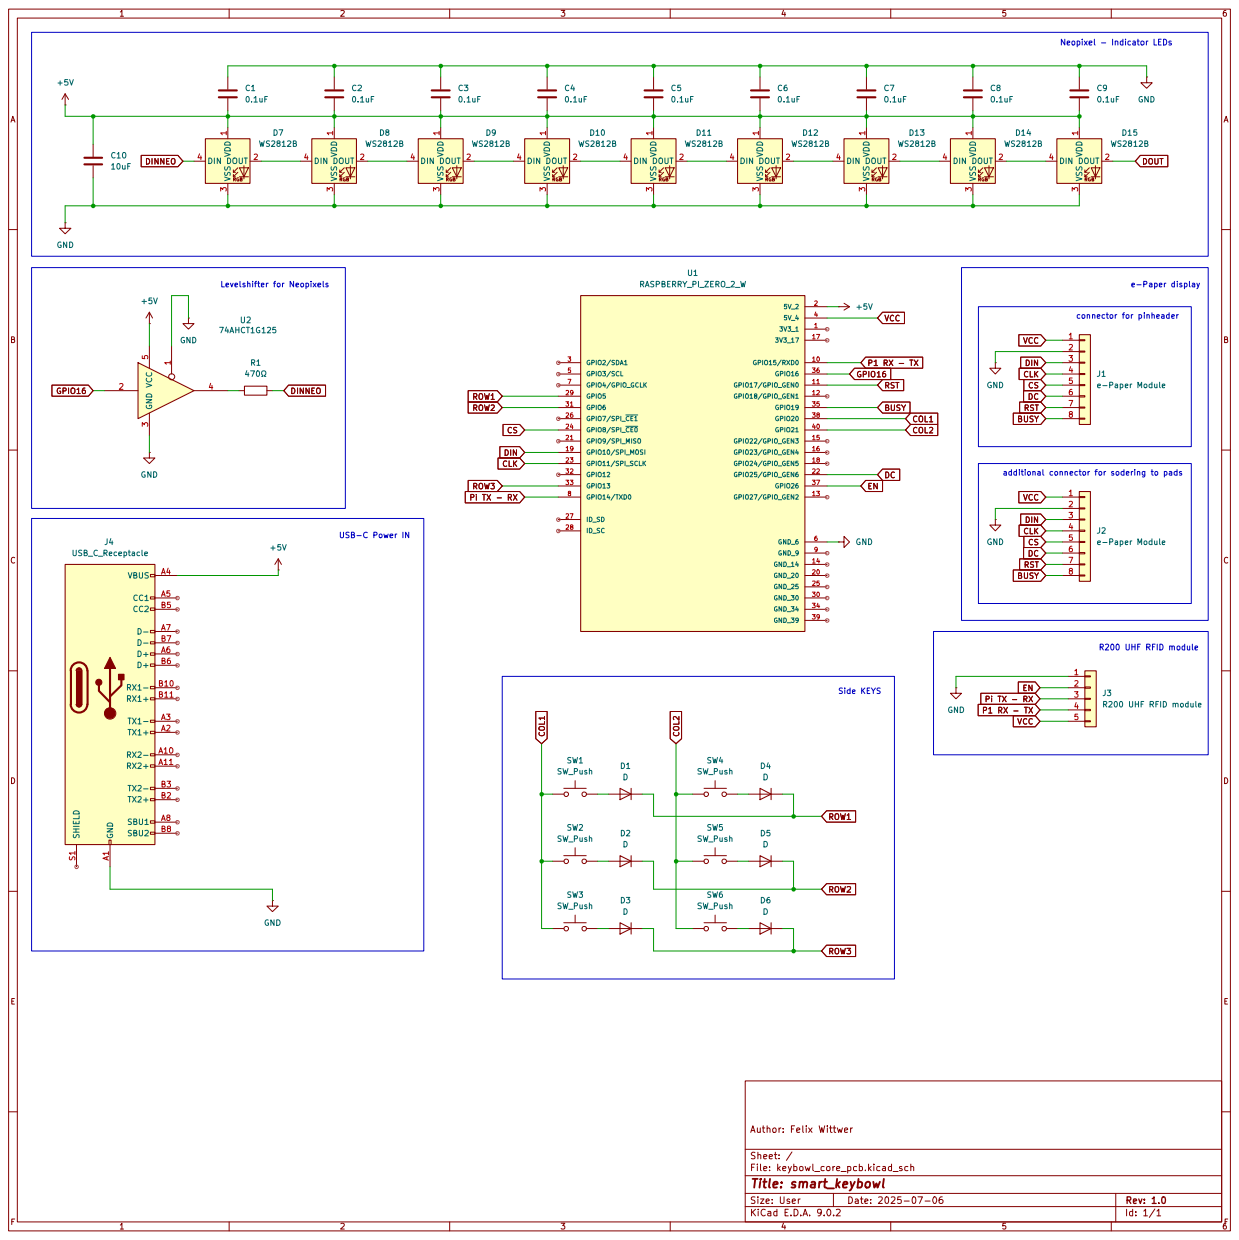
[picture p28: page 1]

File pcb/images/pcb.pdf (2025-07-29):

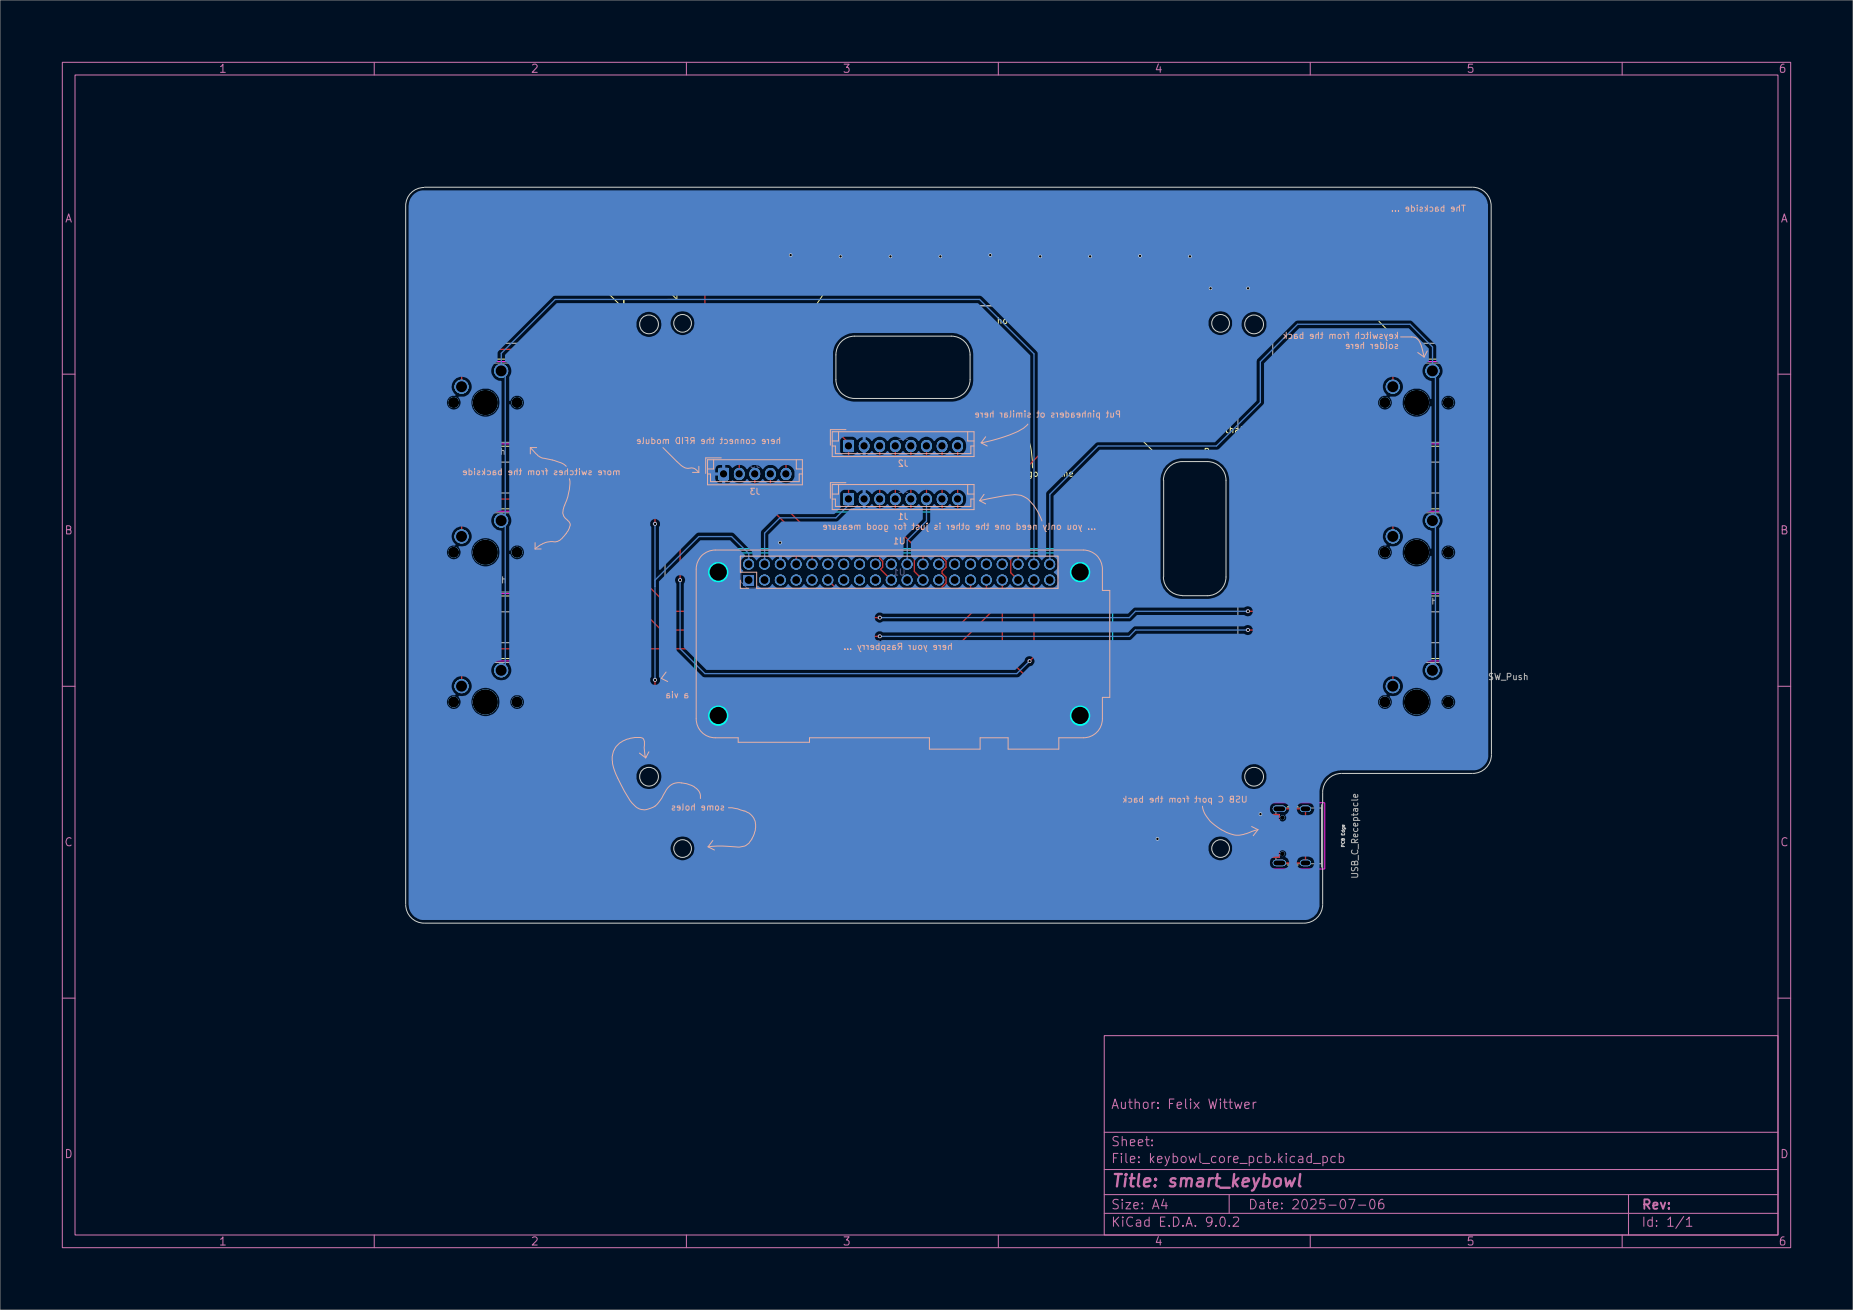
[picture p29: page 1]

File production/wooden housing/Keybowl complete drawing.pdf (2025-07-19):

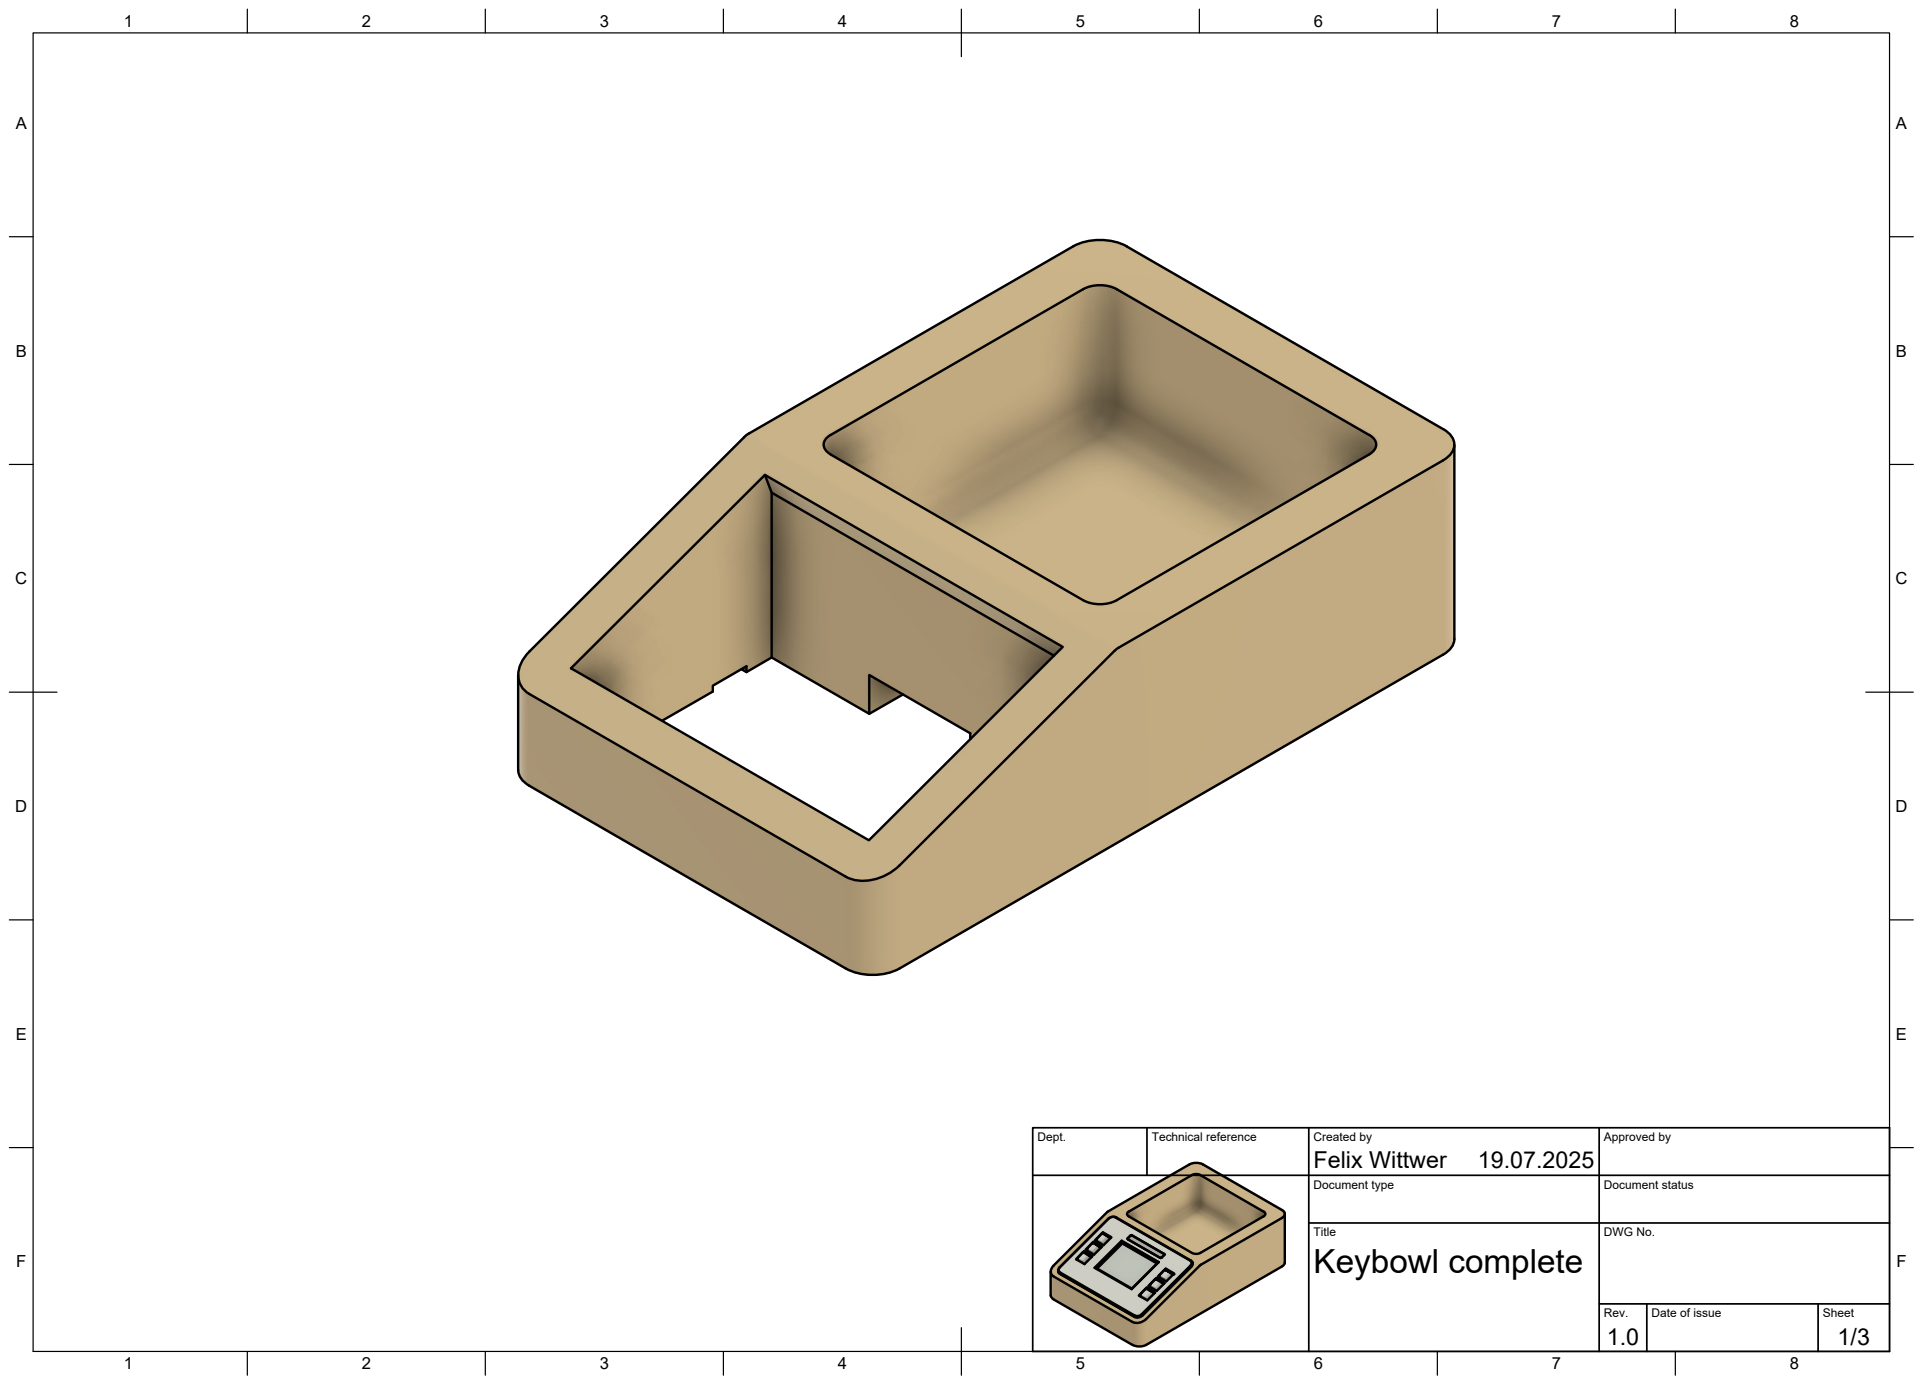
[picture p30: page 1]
Title; DWG No.; Rev.; Date of issue; Sheet; Keybowl complete

Dept. | Technical reference | Created by Felix Wittwer 19.07.2025 | Approved by

Document type | Document status

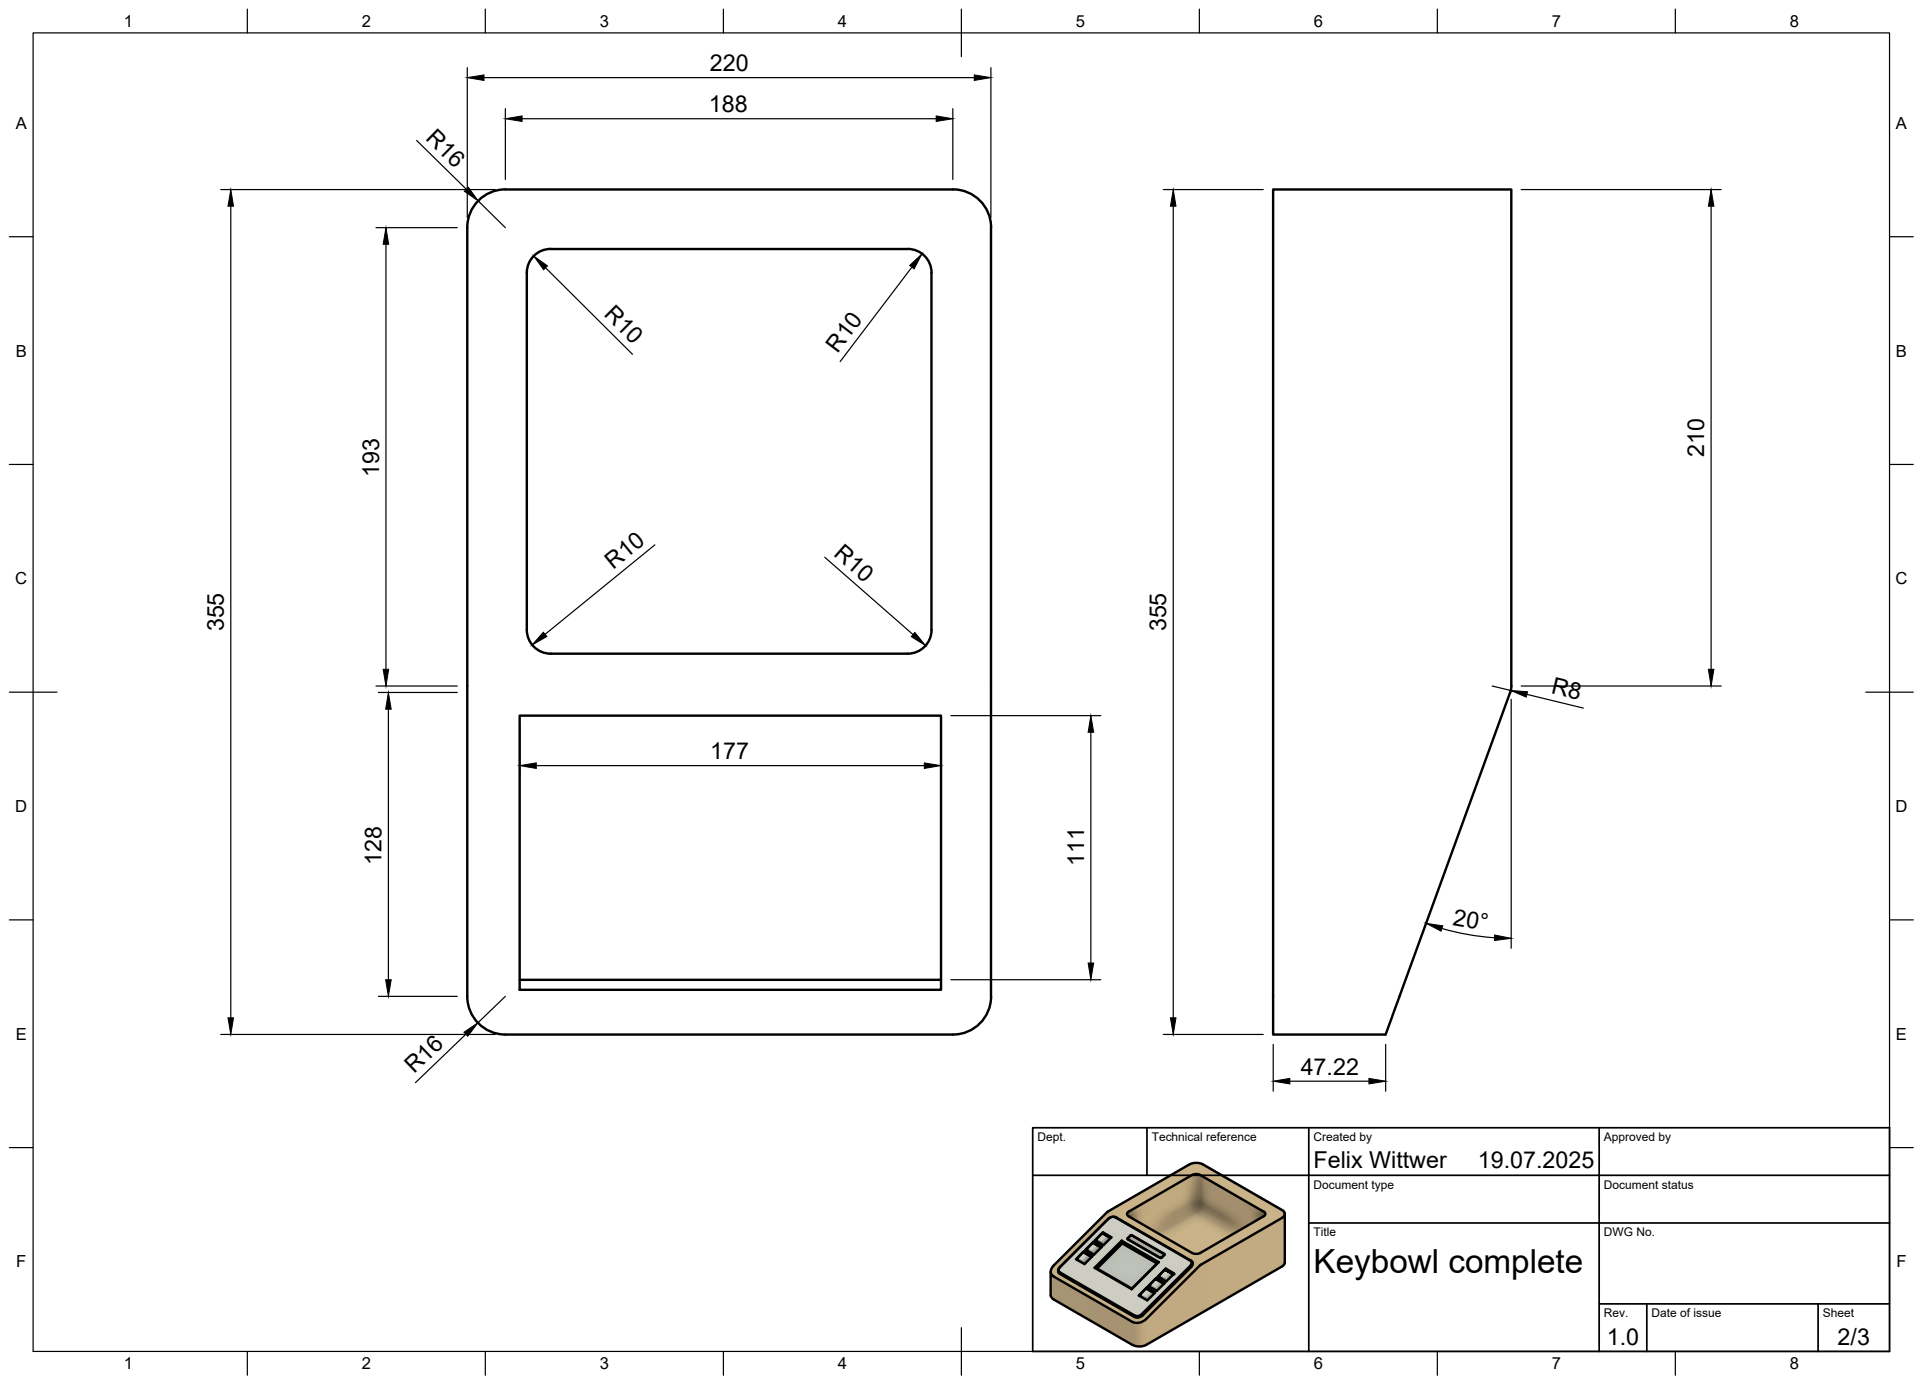
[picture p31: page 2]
Title; DWG No.; Keybowl complete

Dept. | Technical reference | Created by Felix Wittwer 19.07.2025 | Approved by

Document type | Document status

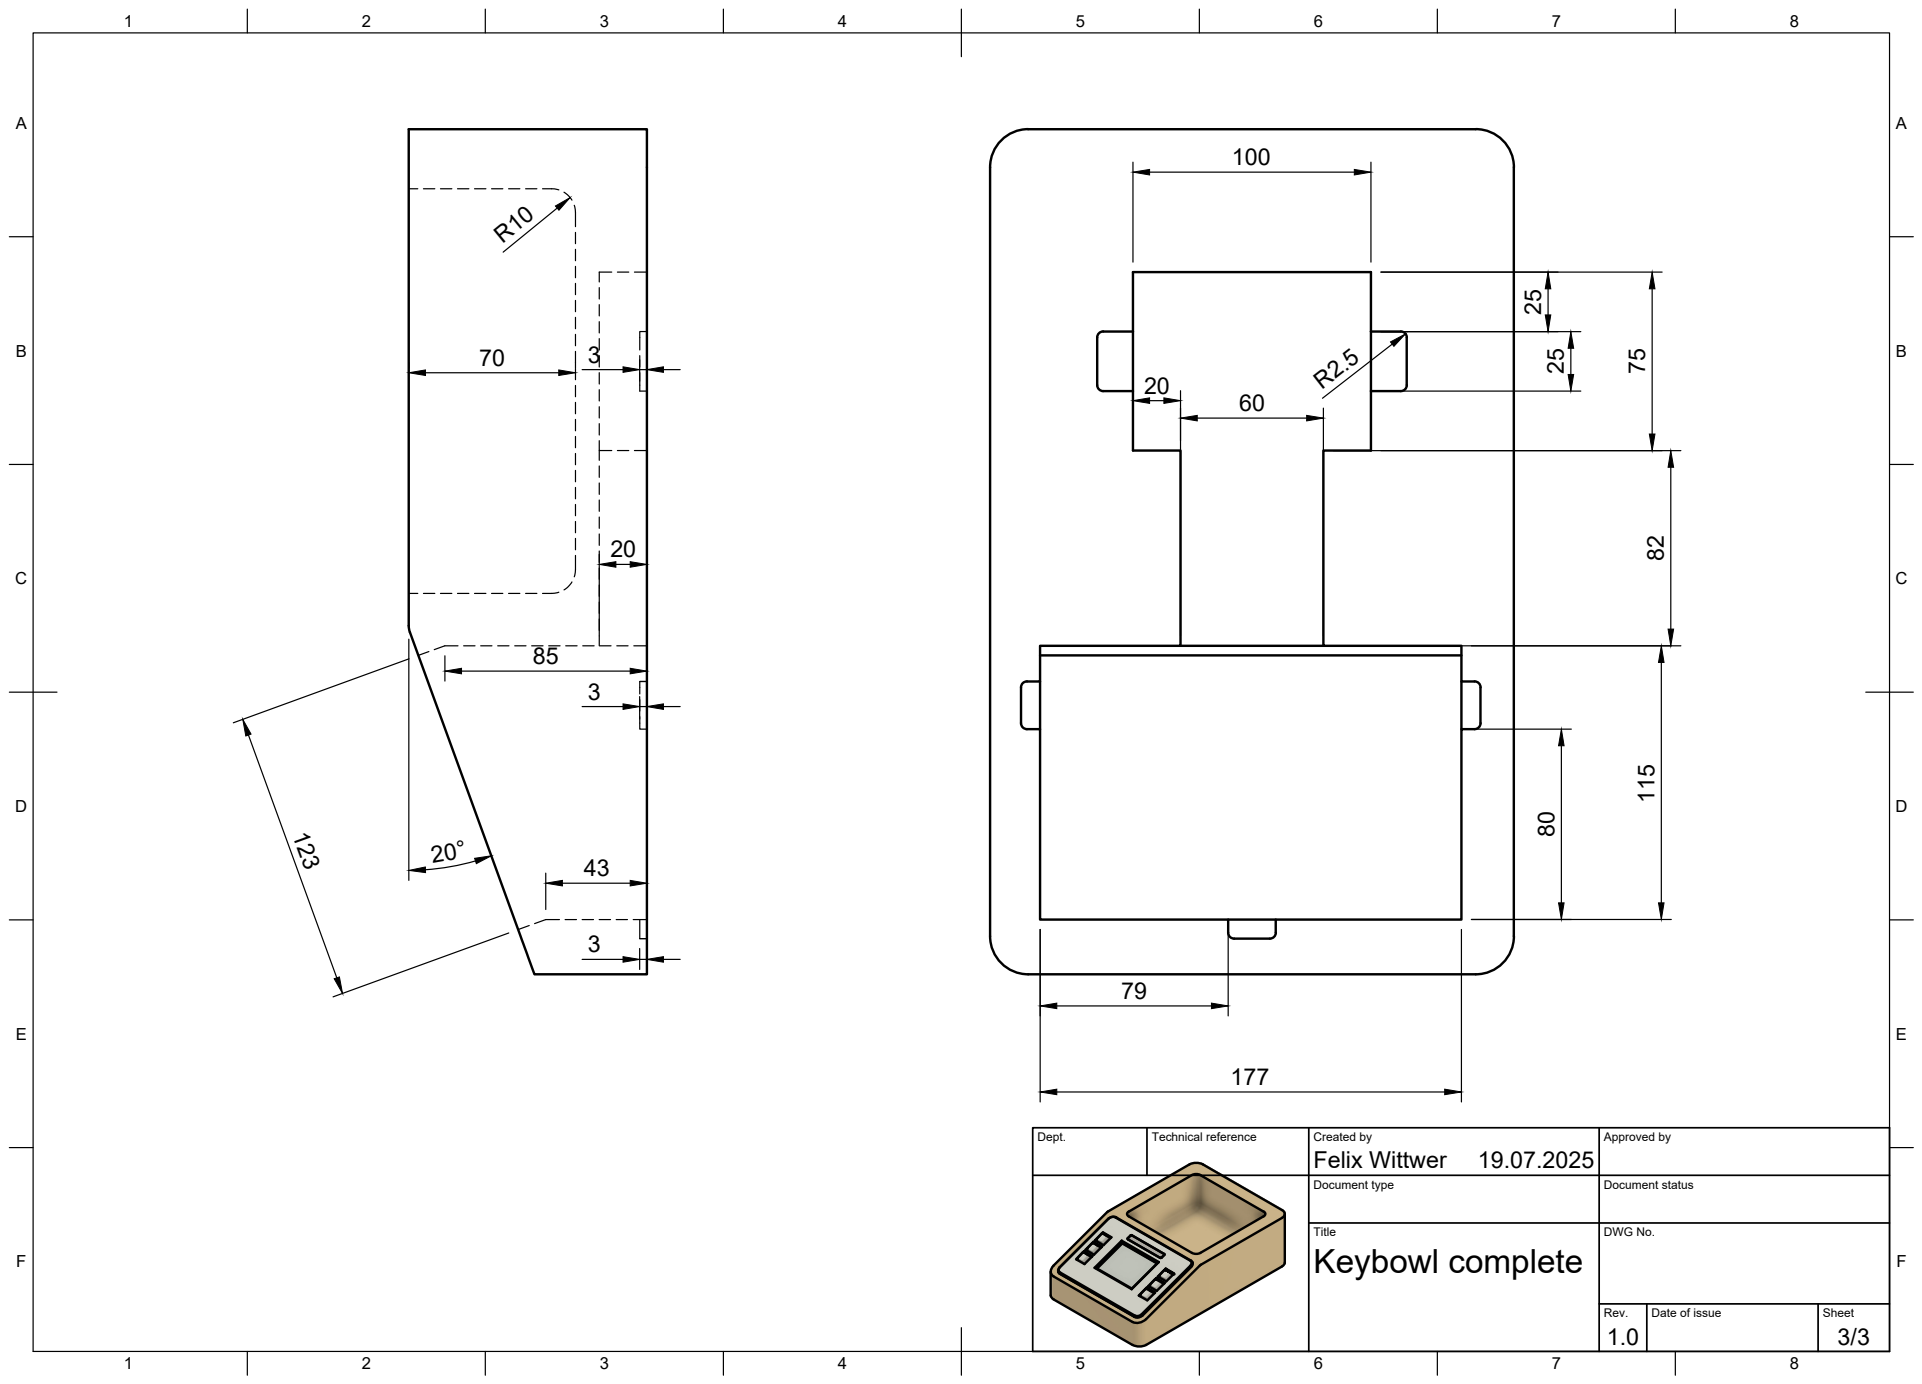
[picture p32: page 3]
Title; DWG No.; Keybowl complete

Dept. | Technical reference | Created by Felix Wittwer 19.07.2025 | Approved by

Document type | Document status

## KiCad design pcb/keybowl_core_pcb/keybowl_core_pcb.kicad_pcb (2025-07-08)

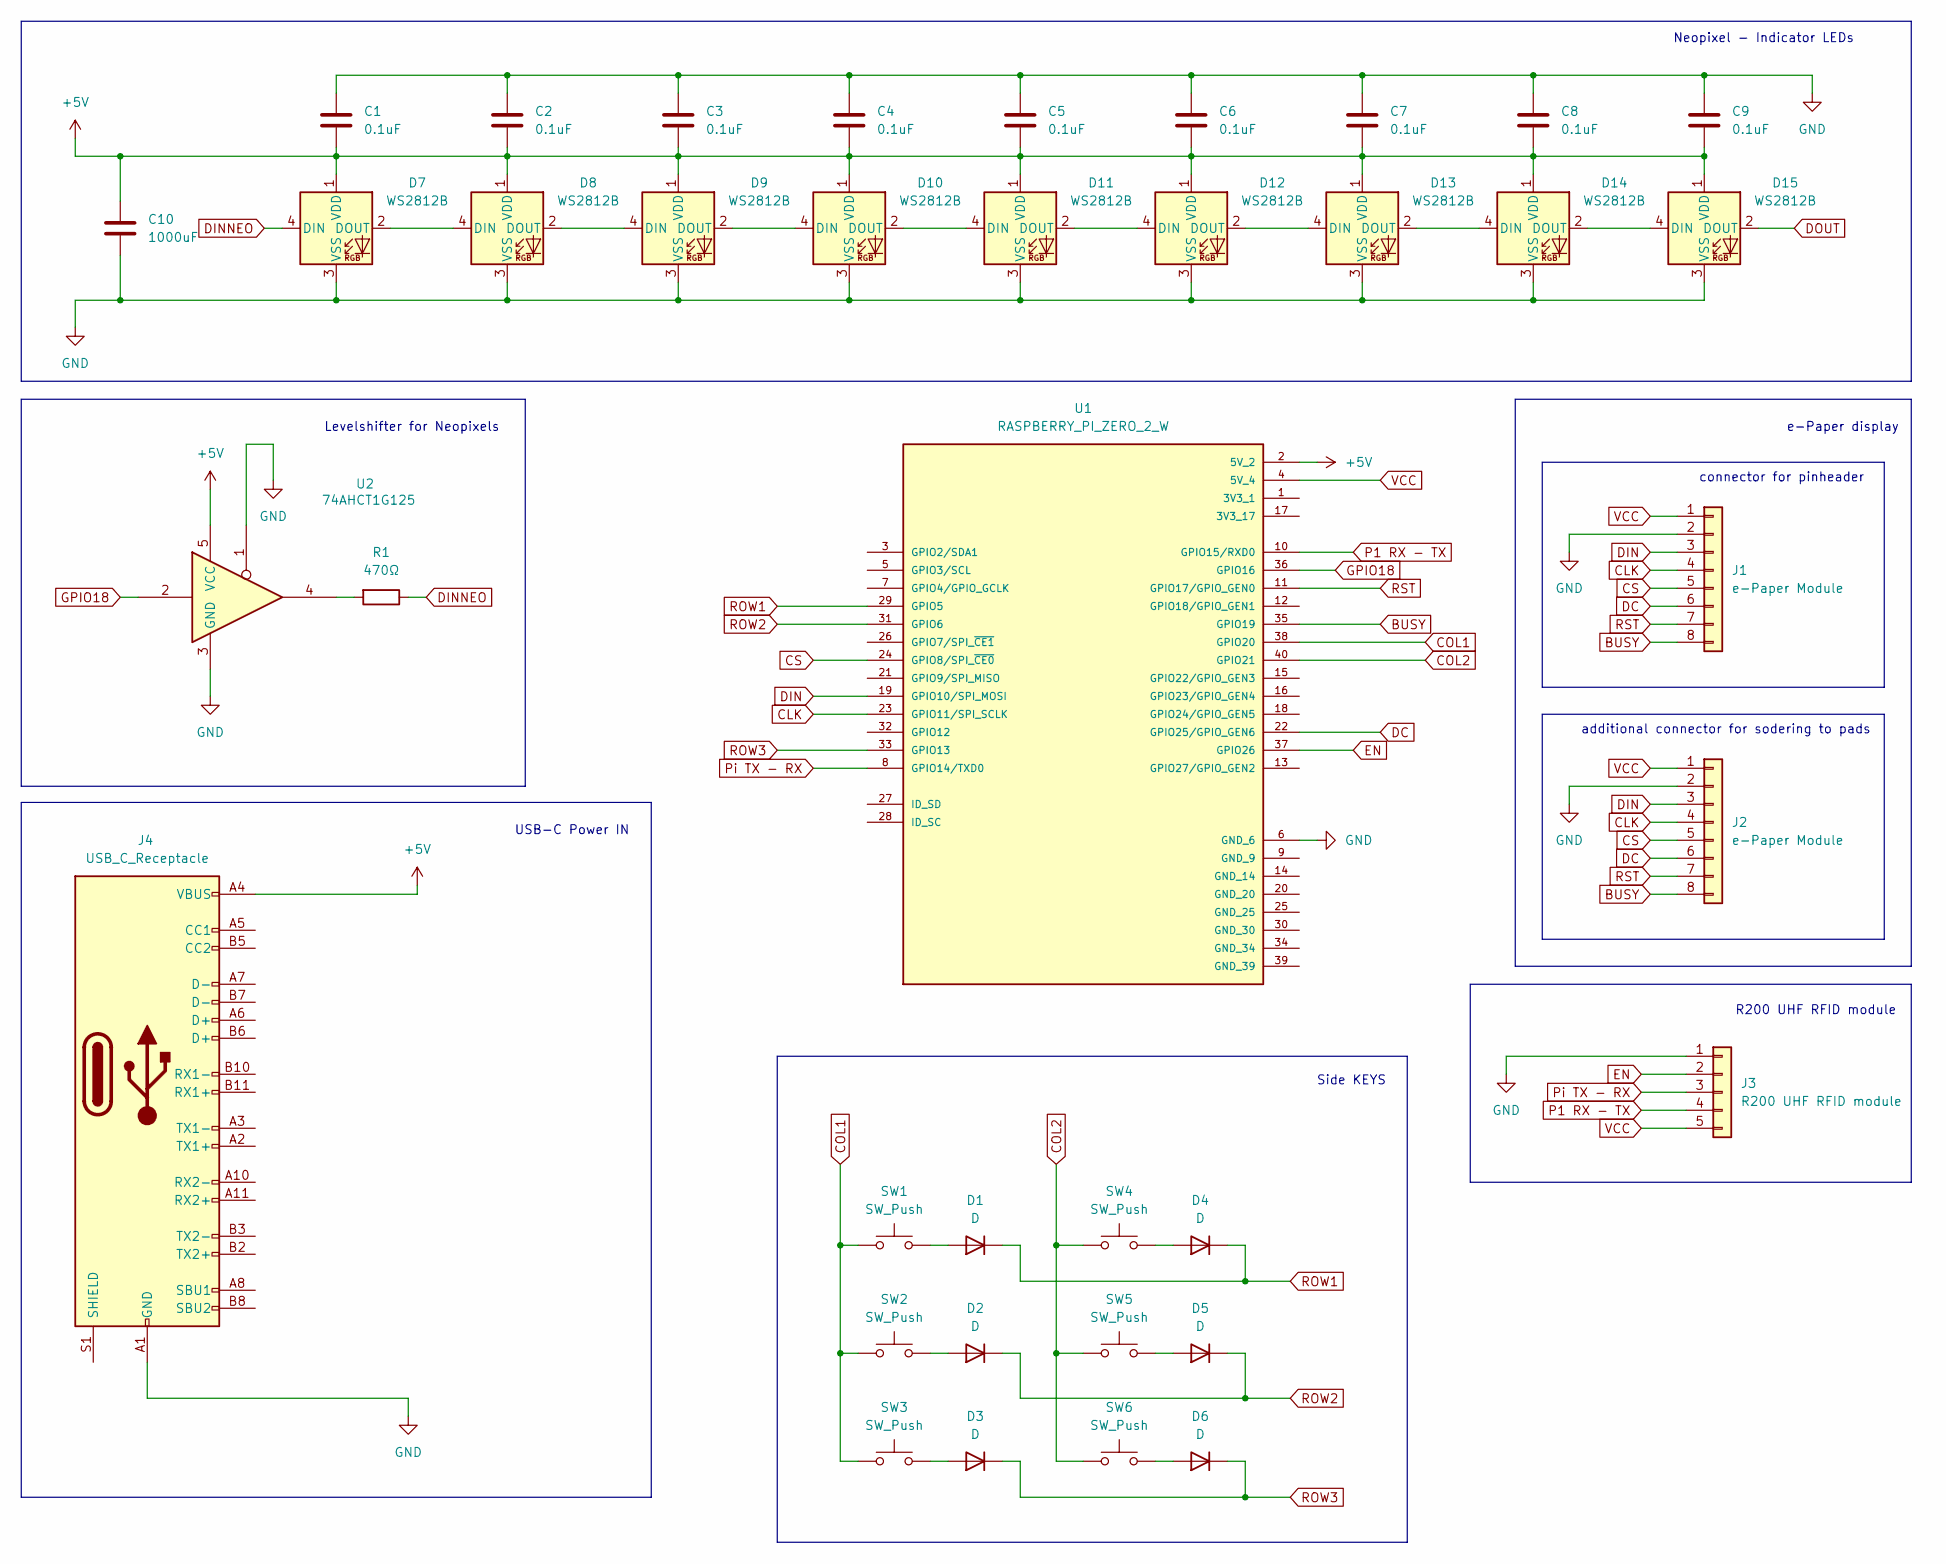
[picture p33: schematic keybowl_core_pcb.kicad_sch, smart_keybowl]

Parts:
C1, C2, C3, C4, C5, C6, C7, C8, C9: 0.1uF; C_0805_2012Metric
C10: 1000uF; C_0805_2012Metric
D1, D2, D3, D4, D5, D6: D; D_0805_2012Metric
D7, D8, D9, D10, D11, D12, D13, D14, D15: WS2812B; LED_WS2812B_PLCC4_5.0x5.0mm_P3.2mm
J1, J2: e-Paper Module; JST_EH_B8B-EH-A_1x08_P2.50mm_Vertical
J3: R200 UHF RFID module; JST_EH_B5B-EH-A_1x05_P2.50mm_Vertical
J4: USB_C_Receptacle; USB_C_Receptacle_GCT_USB4105-xx-A_16P_TopMnt_Horizontal
R1: 470Ω; R_0805_2012Metric_Pad1.20x1.40mm_HandSolder
SW1, SW2, SW3, SW4, SW5, SW6: SW_Push; SW_Cherry_MX_1.00u_PCB
U1: RASPBERRY_PI_ZERO_2_W; Raspberry_Pi_Zero_Socketed_THT_FaceDown_MountingHoles; PARTREV April 2024
U2: 74AHCT1G125; SOT95P280X145-5N

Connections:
+5V: C1.2, C2.2, C3.2, C4.2, C5.2, C6.2, C7.2, C8.2, C9.2, C10.1, D7.1 (VDD), D8.1 (VDD), D9.1 (VDD), D10.1 (VDD), D11.1 (VDD), D12.1 (VDD), D13.1 (VDD), D14.1 (VDD), D15.1 (VDD), J4.A4 (VBUS), J4.A9 (VBUS), J4.B4 (VBUS), J4.B9 (VBUS), U1.2 (5V_2), U2.5 (VCC)
BUSY: J1.8, J2.8, U1.35 (GPIO19)
CLK: J1.4, J2.4, U1.23 (GPIO11/SPI_SCLK)
COL1: SW1.1, SW2.1, SW3.1, U1.38 (GPIO20)
COL2: SW4.1, SW5.1, SW6.1, U1.40 (GPIO21)
CS: J1.5, J2.5, U1.24 (GPIO8/SPI_~CE0)
DC: J1.6, J2.6, U1.22 (GPIO25/GPIO_GEN6)
DIN: J1.3, J2.3, U1.19 (GPIO10/SPI_MOSI)
DINNEO: D7.4 (DIN), R1.1
DOUT: D15.2 (DOUT)
EN: J3.2, U1.37 (GPIO26)
GND: C1.1, C2.1, C3.1, C4.1, C5.1, C6.1, C7.1, C8.1, C9.1, C10.2, D7.3 (VSS), D8.3 (VSS), D9.3 (VSS), D10.3 (VSS), D11.3 (VSS), D12.3 (VSS), D13.3 (VSS), D14.3 (VSS), D15.3 (VSS), J1.2, J2.2, J3.1, J4.A1 (GND), J4.A12 (GND), J4.B1 (GND), J4.B12 (GND), U1.6 (GND_6), U2.1, U2.3 (GND)
GPIO18: U1.36 (GPIO16), U2.2
unnamed: D1.2 (A), SW1.2
unnamed: D2.2 (A), SW2.2
unnamed: D3.2 (A), SW3.2
unnamed: D4.2 (A), SW4.2
unnamed: D5.2 (A), SW5.2
unnamed: D6.2 (A), SW6.2
unnamed: D7.2 (DOUT), D8.4 (DIN)
unnamed: D8.2 (DOUT), D9.4 (DIN)
unnamed: D9.2 (DOUT), D10.4 (DIN)
unnamed: D10.2 (DOUT), D11.4 (DIN)
unnamed: D11.2 (DOUT), D12.4 (DIN)
unnamed: D12.2 (DOUT), D13.4 (DIN)
unnamed: D13.2 (DOUT), D14.4 (DIN)
unnamed: D14.2 (DOUT), D15.4 (DIN)
unnamed: R1.2, U2.4
P1 RX - TX: J3.4, U1.10 (GPIO15/RXD0)
Pi TX - RX: J3.3, U1.8 (GPIO14/TXD0)
ROW1: D1.1 (K), D4.1 (K), U1.29 (GPIO5)
ROW2: D2.1 (K), D5.1 (K), U1.31 (GPIO6)
ROW3: D3.1 (K), D6.1 (K), U1.33 (GPIO13)
RST: J1.7, J2.7, U1.11 (GPIO17/GPIO_GEN0)
VCC: J1.1, J2.1, J3.5, U1.4 (5V_4)

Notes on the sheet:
R200 UHF RFID module
connector for pinheader
Side KEYS
Levelshifter for Neopixels
USB-C Power IN
Neopixel - Indicator LEDs
additional connector for sodering to pads
e-Paper display

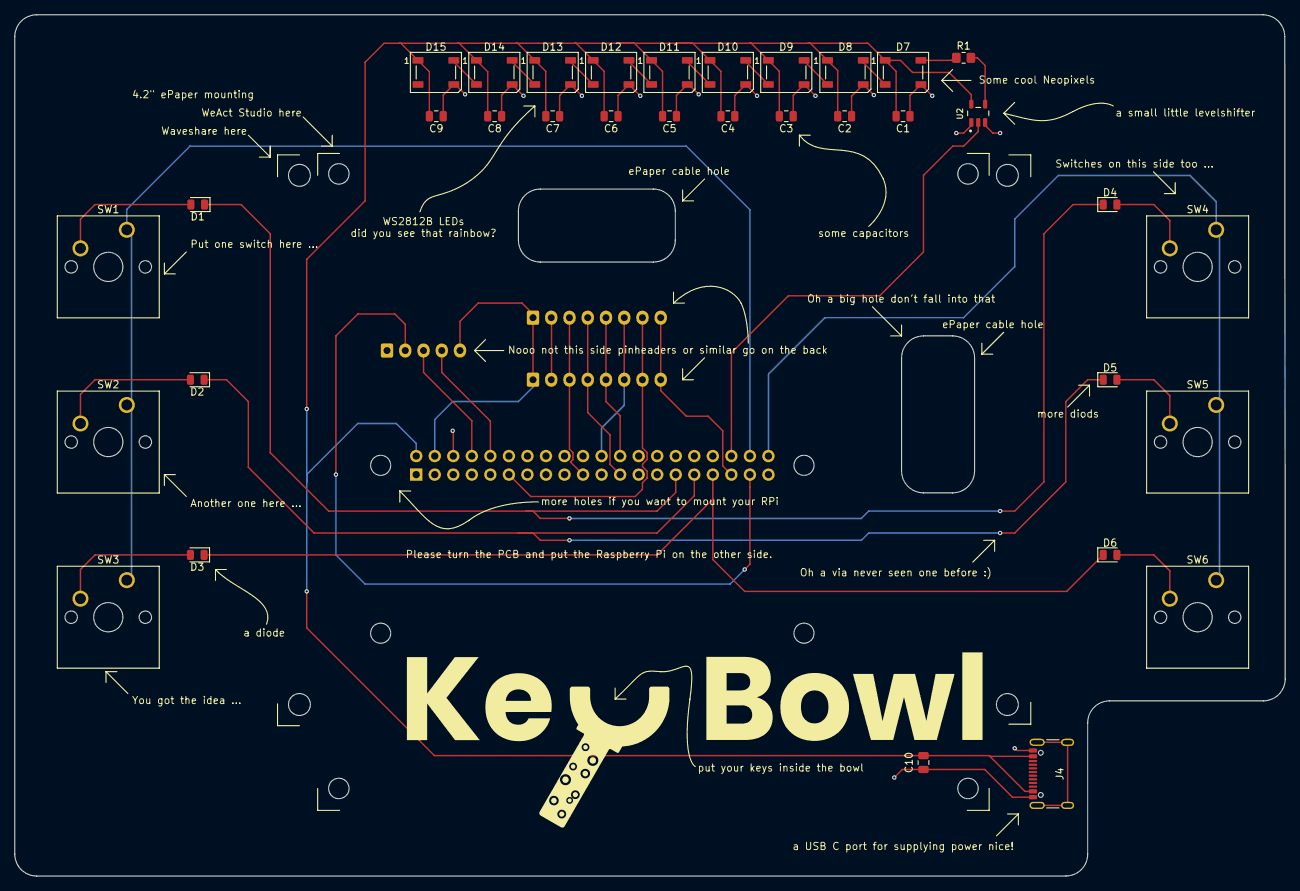
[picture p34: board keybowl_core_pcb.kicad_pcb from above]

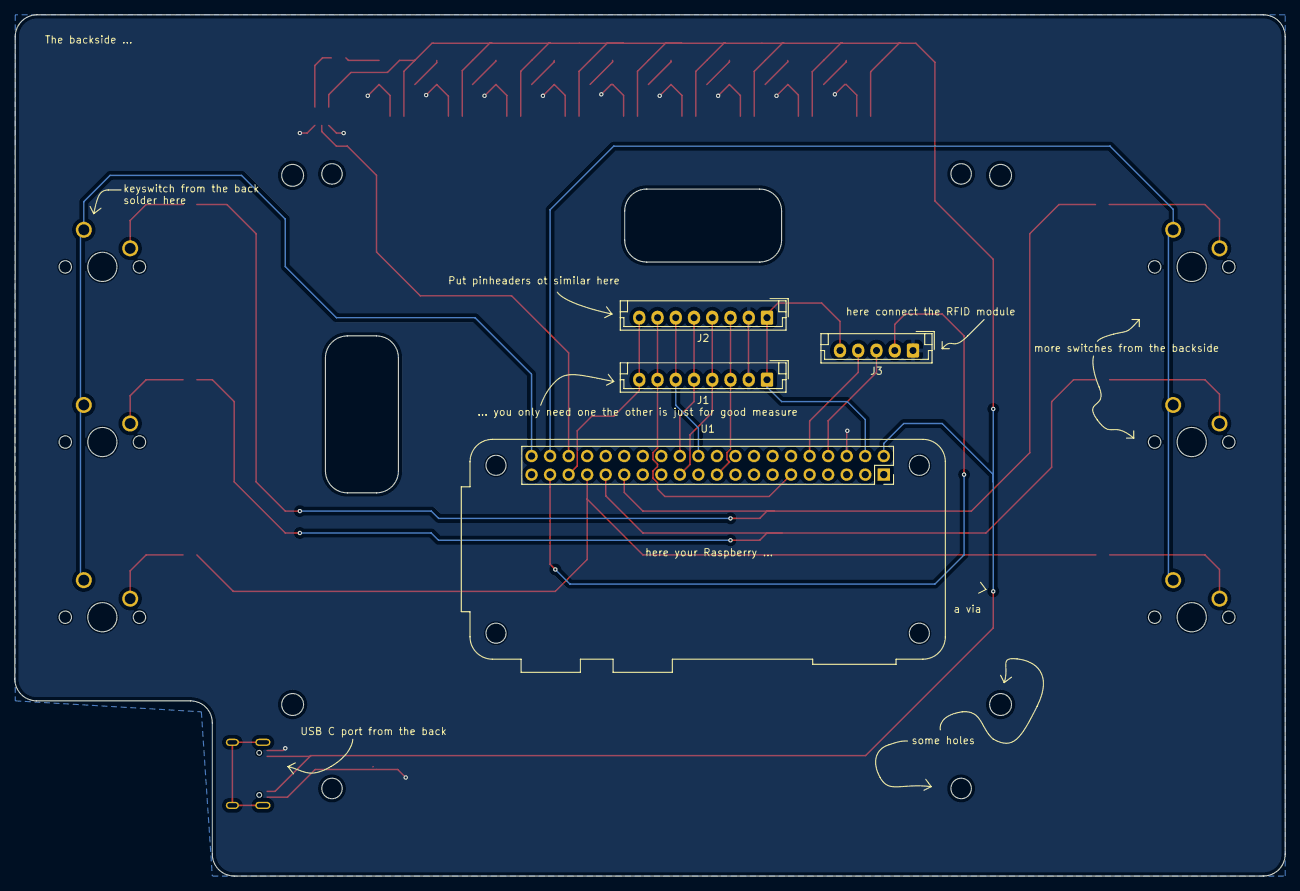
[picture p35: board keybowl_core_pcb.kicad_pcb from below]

Board: 2 copper layers, 174.1 x 118.0 mm, 38 parts (4 on the bottom side), 34 nets.

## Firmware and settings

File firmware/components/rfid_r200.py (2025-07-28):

from pyembedded.rfid_module.rfid import RFID
import time
import json
from pathlib import Path

DB_PATH = Path("key_states.json")

def load_key_db():
    if DB_PATH.exists():
        with open(DB_PATH, "r") as f:
            return json.load(f)
    return {}

def save_key_db(db):
    with open(DB_PATH, "w") as f:
        json.dump(db, f)

key_db = load_key_db()

rfid = RFID(port='/dev/ttyS0', baud_rate=115200, timeout=1)

def read_tags():
    tag_id = rfid.get_id()
    return {tag_id} if tag_id else set()

def check_keys():
    current_tags = read_tags()
    changes = {}

    for tag in current_tags:
        prev_state = key_db.get(tag)
        if prev_state != "present":
            key_db[tag] = "present"
            changes[tag] = "present"

    for tag in list(key_db):
        if key_db[tag] == "present" and tag not in current_tags:
            key_db[tag] = "absent"
            changes[tag] = "absent"

    if changes:
        save_key_db(key_db)

    return changes

if __name__ == "__main__":
    try:
        while True:
            changes = check_keys()
            if changes:
                print("State changes:", changes)
            time.sleep(5)
    except KeyboardInterrupt:
        print("Exiting...")

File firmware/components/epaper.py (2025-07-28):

import spidev
import RPi.GPIO as GPIO
from PIL import Image
import time

DC = 25
RST = 17
BUSY = 19
CS = 8

EPD_WIDTH = 400
EPD_HEIGHT = 300

class EPD:
    def __init__(self):
        self.reset_pin = RST
        self.dc_pin = DC
        self.busy_pin = BUSY
        self.cs_pin = CS
        self.width = EPD_WIDTH
        self.height = EPD_HEIGHT

        GPIO.setmode(GPIO.BCM)
        GPIO.setwarnings(False)

        GPIO.setup(self.reset_pin, GPIO.OUT)
        GPIO.setup(self.dc_pin, GPIO.OUT)
        GPIO.setup(self.cs_pin, GPIO.OUT)
        GPIO.setup(self.busy_pin, GPIO.IN)

        self.spi = spidev.SpiDev(0, 0)
        self.spi.max_speed_hz = 2000000

        self.init()

    def digital_write(self, pin, value):
        GPIO.output(pin, value)

    def digital_read(self, pin):
        return GPIO.input(pin)

    def delay_ms(self, milliseconds):
        time.sleep(milliseconds / 1000.0)

    def send_command(self, command):
        self.digital_write(self.dc_pin, 0)
        self.digital_write(self.cs_pin, 0)
        self.spi.writebytes([command])
        self.digital_write(self.cs_pin, 1)

    def send_data(self, data):
        self.digital_write(self.dc_pin, 1)
        self.digital_write(self.cs_pin, 0)
        if isinstance(data, list):
            self.spi.writebytes(data)
        else:
            self.spi.writebytes([data])
        self.digital_write(self.cs_pin, 1)

    def wait_until_idle(self):
        while self.digital_read(self.busy_pin) == 0:
            time.sleep(0.1)

    def reset(self):
        self.digital_write(self.reset_pin, 1)
        self.delay_ms(200)
        self.digital_write(self.reset_pin, 0)
        self.delay_ms(2)
        self.digital_write(self.reset_pin, 1)
        self.delay_ms(200)

    def init(self):
        self.reset()
        self.send_command(0x01)  # POWER SETTING
        self.send_data(0x03)
        self.send_data(0x00)
        self.send_data(0x2b)
        self.send_data(0x2b)

        self.send_command(0x06)  # BOOSTER SOFT START
        self.send_data(0x17)
        self.send_data(0x17)
        self.send_data(0x17)

        self.send_command(0x04)  # POWER ON
        self.wait_until_idle()

        self.send_command(0x00)  # PANEL SETTING
        self.send_data(0x3F)

        self.send_command(0x30)  # PLL CONTROL
        self.send_data(0x3C)

        self.send_command(0x61)  # RESOLUTION SETTING
        self.send_data((self.width >> 8) & 0xFF)
        self.send_data(self.width & 0xFF)
        self.send_data((self.height >> 8) & 0xFF)
        self.send_data(self.height & 0xFF)

        self.send_command(0x82)  # VCOM Voltage
        self.send_data(0x28)

        self.send_command(0X50)  # VCOM AND DATA INTERVAL SETTING
        self.send_data(0x97)

    def display_image(self, image: Image.Image):
        # Convert image to 4-level grayscale and then to 2-bit
        image = image.convert("L").resize((self.width, self.height))
        buf = self._image_to_2bit(image)

        self.send_command(0x10)
        self.send_data(buf)

        self.send_command(0x12)  # Display Refresh
        self.wait_until_idle()

    def _image_to_2bit(self, image):
        levels = [0, 85, 170, 255]
        pix = list(image.getdata())
        buf = bytearray()

        for i in range(0, len(pix), 4):
            b = 0
            for j in range(4):
                if i + j >= len(pix):
                    level = 0
                else:
                    gray = pix[i + j]
                    if gray < 64:
                        level = 0b00
                    elif gray < 128:
                        level = 0b01
                    elif gray < 192:
                        level = 0b10
                    else:
                        level = 0b11
                b |= (level << (6 - 2 * j))
            buf.append(b)
        return buf

    def sleep(self):
        self.send_command(0x02)  # POWER OFF
        self.wait_until_idle()
        self.send_command(0x07)  # DEEP SLEEP
        self.send_data(0xA5)

    def clear(self):
        blank = Image.new("L", (self.width, self.height), 255)
        self.display_image(blank)

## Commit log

2025-07-06 start adding pcb
    [SN74AHCT1G125DBVR.step, keybowl_core_pcb.kicad_pcb, keybowl_core_pcb.kicad_sch]
2025-07-08 working on pcb
    [keybowl_core_pcb.kicad_pcb]
2025-07-18 add assembled pcb
2025-07-19 add housing and mounting
2025-07-19 add prduction files and instructions - instructions on building the wooden base
    [bezzle.step, bezzle.stl, neopixel_diffusor.step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]
2025-07-28 adding firmware and fix small issue inside schematic
    [keybowl_core_pcb.kicad_sch]
2025-07-29 getting ready for submission
    [BOM.csv, keybowl_bom.xlsx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]
2025-07-29 getting really ready for submission
    [Keybowl complete.3mf, bowl.step]
2025-07-29 small chnages on the pcb and extend BOM to PCB assembly parts
    [keybowl_bom.xlsx, keybowl_core_pcb.kicad_sch]
2025-07-29 add hint for unpopulated PCB parts
